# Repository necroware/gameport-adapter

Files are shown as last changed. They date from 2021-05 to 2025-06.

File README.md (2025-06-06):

# Necroware's GamePort Adapter

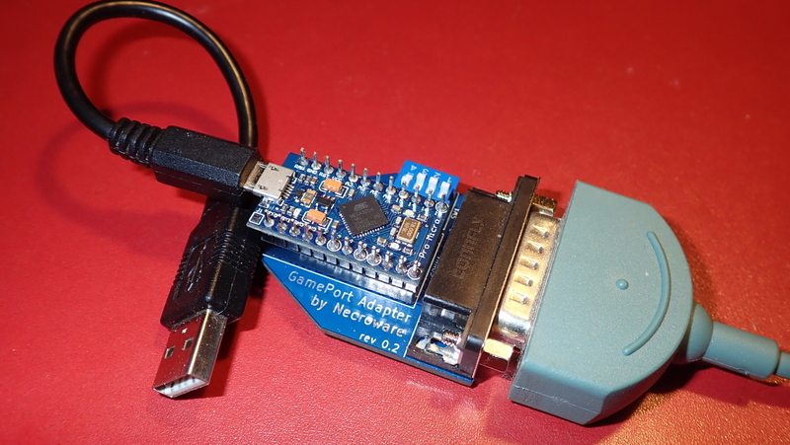
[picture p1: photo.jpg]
GamePort Adapter


Many people from the retro community still have their beloved joysticks and
gamepads from the early days. These devices often live their lives somewhere in
the dark corners of our basements and we don't dare to throw them away, because
of nostalgic reasons. They remind us so much of our childhoods, where we played
our Wing Commanders, X-Wings, Descents and many other games. These old joysticks
were all made to be connected to the game port, usually on a sound card. But
by the end of 90's and beginning of 2000's game ports vanished from our
computers and were replaced by USB and our old joysticks disappeared into the
past. Today not everybody has a full retro PC and many people are using their
modern computer with  DOSBox to play the old games, sometimes with a modern
USB joystick. But wouldn't it be great to play the old games with the same
joystick which we used back then? And this is where this adapter comes into
play. It can be used to connect gameport joysticks to a USB port.

GamePort Adapter Videos:
* [Part 1: Introduction](https://youtu.be/tSJLgCD8jeM)
* [Part 2: Updates](https://youtu.be/947DewHwbsE)

## How does it work?

The adapter is built around Arduino Pro Micro, which uses the same ATmega32U4
microcontroller as Leonardo. This microcontroller has built-in USB HID
capabilities and can be used to build HID input devices, like joysticks. The
adapter itself is super simple, the main brainwork was invested into the
software. Very much simplified, it reads the joystick states and sends the data,
via USB, to the computer, which thinks that it is communicating with a USB 
joystick.

## What is special about this one?

There are already plenty of gameport to USB adapters for basic analog joysticks
and, as far as I know, there were some efforts to communicate with Sidewinder
joysticks by Microsoft as well. But there is no universal adapter, which would
work with different types of joysticks. This adapter implements multiple drivers
for various analog and digital joysticks, with an option to add more, in the 
future.

Features overview:
* Support for generic analog joysticks with 2/4 buttons and 2/4 axes
* Four switches to select joystick type
* Autodetection for various digital protocol joysticks
* Auto-Calibration
* Very low input lag

## What is the difference between analog and digital joystick?

Many people call button-only joysticks or gamepads digital. This is kind of
right, because a button is either pressed or not. You can't have an analog
values in between. However by digital, in this case, we mean something different.
A gameport contains 15 pins, 8 of which are used for joystick communication. 4
pins are for buttons and carry digital values in sense of on/off and 4 pins are
for analog axes, which deliver voltage somewhere between 0V and 5V. Joysticks
which were made in the early days used this pinout. They could have a
maximum of 4 buttons and 4 axes and were DOS compatible. Later, in the time of
Windows 95/98 many joysticks were made to be plugged into a gameport as well,
but they were not limited to 4 buttons and 4 axes. They had a lot more exciting
features, like hat switches and throttle controls. But how did this work? Well
the manufacturers implemented their drivers to communicate with the joystick via
gameport using a proprietary communication protocol. For example, by using one
pin of the gameport as clock and another one as data, the possibilities were
almost limitless. Such joysticks are called digital as well, because they used
digital protocols to communicate with the PC. And suddenly, many features were
possible, but the price of these features was the lost compatibility to DOS. You
couldn't just plug such a joystick into the gameport and expect it to work in
old DOS games. The plug was the same, but the signaling was completely different.

## Which joysticks does this adapter support?

Currently, the following drivers are implemented. To select the right driver, you
have to use four switches, as shown in the table. The switches may be changed or
extended in the future, so please pay attention to the updates.

Joystick Model               | Buttons | Axes  |  Hat | SW1-4 | Protocol   | Comments
-----------------------------|---------|-------|------|-------|------------|------------------------------------
Generic Analog               | 2       | 2     | 0    | 0000  | Analogue   |
Generic Analog               | 4       | 2     | 0    | 1000  | Analogue   |
Generic Analog               | 4       | 3     | 0    | 0100  | Analogue   | 3rd Axis is throttle
Generic Analog               | 4       | 4     | 0    | 1100  | Analogue   |
CH FlightStick               | 4       | 4     | 1    | 0010  | Analogue   |
CH F16 Combat Stick          | 10      | 3     | 1    | 0110  | Analogue   |
ThrustMaster                 | 4       | 3     | 1    | 1010  | Analogue   | FCS MARK I/II & PFCS
Sidewinder GamePad           | 10      | 2     | 0    | 1110  | Sidewinder |
Sidewinder 3D Pro            | 8       | 4     | 1    | 1110  | Sidewinder |
Sidewinder 3D Pro Plus       | 9       | 4     | 1    | 1110  | Sidewinder | First version of Precision Pro
Sidewinder Precision Pro     | 9       | 4     | 1    | 1110  | Sidewinder |
Sidewinder FFB Pro           | 9       | 4     | 1    | 1110  | Sidewinder | FFB not yet implemented
Sidewinder FFB Wheel         | 8       | 3     | 0    | 1110  | Sidewinder | FFB not yet implemented
Gravis GamePad Pro           | 10      | 2     | 0    | 0001  | GrIP       |
Logitech WingMan Extreme     | 6       | 3     | 1    | 1001  | ADI        |
Logitech CyberMan 2          | 8       | 6     | 0    | 1001  | ADI        |
Logitech WingMan Interceptor | 9       | 3     | 3    | 1001  | ADI        | 2 hats are mapped as 4 axes
Logitech ThunderPad Digital  | 8       | 2     | 0    | 1001  | ADI        | Directional buttons mapped as 2 axes
Logitech WingMan Gamepad     | 11      | 2     | 0    | 1001  | ADI        | Directional buttons mapped as 2 axes
Logitech WingMan Light       | 2       | 2     | 0    | 0000  | Analogue   |

*Remarks:*

- Please pay attention to how the same switches are used for different families
of digital devices. This is possible due to fully digital communication. Using
this method, the adapter implements autodetection as soon as it knows, that it
is connected to a digital joystick.
- Currently, only the drivers for the listed Sidewinder devices are implemented,
since I have no other models at hand. The Precision Pro works natively on USB
as well, but was still implemented, because we can.
- Gravis used their GrIP protocol, which is currently implemented only for the
Gravis GamePad Pro, but without daisy chaining possibility so far.
- The implementation of the ADI protocol used by Logitech should work with all
the devices which support that protocol. However only the listed Logitech devices 
were tested so far.

## Which joysticks were tested?

Many joysticks in the wild are using the same digital protocol or are backwards
compatible to the analog joysticks as they were used back in the days in DOS.
Following list contains all the devices which were reported by others as working
so far:

* CH Mach I+ (analog, 2-axes, 2-buttons)
* Gravis Analog Pro (analog)
* Gravis GamePad Pro
* Gravis PC GamePad (analog)
* InterAct UltraRacer PC (analog)
* Logitech CyberMan 2
* Logitech WingMan Extreme Digital
* Logitech WingMan Interceptor
* Logitech WingMan Light
* Logitech ThunderPad Digital
* Logitech WingMan Gamepad
* Medion Joypad MD9823 (analog, 4-axes, 4-buttons)
* QuickShot QS-123E "Warrior 5" (analog)
* Quickshot QS-146 "Intruder 5" (analog)
* Quickshot QS-151 "Aviator" (analog)
* QuickShot QS-201 "Super Warrior" (analog)
* QuickShot QS-203 "Avenger" (analog)
* Sidewinder 3D Pro
* Sidewinder 3D Pro Plus
* Sidewinder ForceFeedBack Pro
* Sidewinder ForceFeedBack Wheel
* Sidewinder GamePad
* Sidewinder Precision Pro 

Sidewinder 3D Pro can be switched between analog and digital mode and in analog
mode it can emulate the ThrustMaster and CH FlightStick. That's why you see them in
the table above. Unfortunately I don't possess those joysticks in reality, so it may
be that the implementation is not quite correct.

## What is auto calibration?

Old analog joysticks have resistors inside, which are specified to be 100 kOhm.
Unfortunately, these resistors are either worn out, bad quality or were wrong from
the beginning. Therefore most of the generic analog joysticks had adjustment
screws to correct the center point of the joystick. Also many games had
calibration options in their settings to readjust the joystick. With USB and new
digital solutions the calibration was not required anymore and was completely
implemented in the joysticks and/or drivers. Many modern games have no option
to re-calibrate the joystick anymore. If we try to play such newer games with
an old analog joystick through this adapter, the joystick center point would be
totally offset. That's why the adapter implements auto calibration internally and
presents already corrected values to the operation system. 

__ATTENTION__: a hard requirement for using the analog joysticks is that during 
plugging into the USB port all axes must be in their middle state, because all
the subsequent calibration happens based on the initial state.

## Technical insights into implementation

The code is well documented, so if you are interested in the details, feel free
to take a look into the driver implementation. All the analog joysticks were
actually a straight forward task, but the Sidewinder digital protocol was kind 
of tough. There are already some implementations of Sidewinder protocol made for
Arduino. However, they are mostly only for the Sidewinder GamePad and not really 
universally made. In the end I was heavily inspired by the Linux Sidewinder 
driver implementation. The code you can see in this project is a complete rewrite, 
I just took the Linux driver implementation as a reference to understand how it 
works. Also the Sidewinder patent US#5628686A helped a lot, especially with 
switching between digital and analog mode for Sidewinder 3D Pro.

In opposition to the already mentioned Sidewinder for Arduino implementations,
this one doesn't rely on interrupts. This implementation is from a similar idea 
to what the Linux driver does. It polls the port and makes a lot of things
simpler due to synchronous process. The biggest problem was that the Sidwinder
devices send the data incredibly fast, with a clock pulse of only 5us. It was
not possible to use Arduino's digitalRead(...) function for that. It was too
slow with about 2.7us per call on an Arduino Pro Micro of 16MHz.  It simply
made it impossible to poll 5us pulses, with such a slow function, not even
considering doing something with the data in between. So out of that need, my 
own implementation came about, which is up to 50% faster and needs only about 
1.6us per call, on the same hardware. The custom I/O functions made it possible
to read the data with the speed which a Sidewinder joystick requires. The best 
part is that the code is written in pure C++. It is very simple to read and to 
use. There are no macros, no assembler or any dirty hacks, just a lot of
optimization.

## Bill of materials (BOM)

The hardware is super simple. To build an adapter you'll need the PCB from this
project and following parts:

Part    |  Qty  | [LCSC](https://lcsc.com/) #  | [Digikey](https://www.digikey.com/) #                | [Mouser Electronics](https://www.mouser.com/) # | Comment
--------|-------|---------|--------------------------|----------------------|------------------------------------------
CONN1   |   1   | C77835  | 609-5371-ND              | 523-L77SDA15SA4CH4F  | DB15 female connector
R1..R4  |   4   | C172965 | 13-MFR-25FTE52-100KCT-ND | 603-MFR-25FTE52-100K | 100 kOhm resistors
SW1     |   1   | C15781  | 2449-KG04ET-ND           | 642-DS04T            | DIP-4 switch
U1      |   1   | C72120  | ED3051-5-ND              | 649-DILB24P-223TLF   | DIP24 Socket (optional)
U1      |   1   |   N/A   | 1568-1060-ND             | 474-DEV-12640        | Arduino Pro Micro (ATmega32U4 16MHz, 5V), including two 12 pin header connectors, MicroUSB version (see "Known issues")

## Known issues

* *Some axes on an analog joystick are offset*

   Auto calibration requires all the axes to be in the center position during 
   initialization. Please see the paragraph about auto calibration.

* *Joystick doesn't work*

   Make sure that you are using one of supported joysticks or a joystick which can
   work in legacy analog mode

* *MicroUSB port on the Arduino is not stable enough*

   Use the USB-C version of the Arduino instead.  
   Or always keep the MicroUSB cable attached to the Arduino MicroUSB version to avoid further wear and apply plug/unplug operations only on the remote side of the cable.

## How to help the project?

The best way is to implement more drivers. Since I have only the joysticks
mentioned above, I can't contribute more than what is currently included.

## Special thanks

I would like to give some special thanks to *Creopard* from the German 
dosreloaded.de community for providing me the mentioned joysticks. Without that
donation this project wouldn't be possible. Especially dealing with Sidewinder
3D Pro was a very exciting task.

## Links
* [Linux Sidewinder Driver](https://github.com/torvalds/linux/blob/master/drivers/input/joystick/sidewinder.c)
* [Sidewinder patent](https://patents.google.com/patent/US5628686A/en)
* [Creopard Retro Site](https://www.creopard.de/)

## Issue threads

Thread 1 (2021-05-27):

digital mode switching necessary?

git-moritz, 2021-05-27:
as far as I understand, we don't need to initialize the Sidewinder 3D Pro into "digital transfer mode" at all... every "trigger" causes the joystick to transmit a 64-bit-package, regardless of mode. the only advantage of digital mode is that IF we use both trigger lines (X1 and Y2), the joystick will transfer triplets instead of bits, which allows for transmission error correction.

since we are only using single-line-transfer, is there any reason why we even _try_ to switch into digital mode?

necroware, 2021-05-27:
Hi Moritz and thank you for the donation first of all :)

We need to switch into digital mode even when using only single line transfer. In analog mode joystick will not react on any trigger signals and will instead emulate CH FlighStick or Thrustmaster analogue joystick, dependent on the current joystick setting.  You can just use the 3D Pro in CH FlightStick mode as well, it is already a feature rich configuration, but in that case you would only have 4 buttons and the hat switch would only work in 4 ways. To use the full features set of the 3D Pro, you need to set it into digital mode.

git-moritz, 2021-05-27:
that's actually not true :)
I used parts of your code to make a sketch that only uses readPacket (via readState) without ever calling enableDigitalMode, and it works just as well.
This behavior is in fact documented in US Patent # 5628686A:

**"The first interrupt request is interpreted by the digital joystick 102 as the Send Data command. In response to the Send Data command, the digital joystick 102 transmits the 64-bit data packet with digital position data and button data, as described above."**

(the sequence that switches the stick into digital mode consist of four interrupt requests - the first of these is already a "Send Data" command!)

**"A single mode data bit is also included in the 64-bit data packet. The mode data bit indicates whether the digital joystick 102 is operating in the Digital Transmission Mode 300 (see FIG. 4) or in the Analog Emulation Mode 302 as well as the type of conventional joystick 10 being emulated if in the Analog Emulation Mode."**

The 64-bit-packet can be transmitted in ANY mode, and even _tells_ you the mode it's currently in. (We could, in fact, even use the mode switch as an additional input "button"...)

necroware, 2021-05-27:
Which joystick did you use to test it? At least on my 3D Pro it doesn't work. The initial state is analog mode and you can try to trigger it as much as you want, you'll get no response. I analyzed it with logic analyzer and without the "magic sequence" it doesn't do anything. I'll get two more Sidewinder joysticks in the next days, one is again a 3D Pro the other is Precision Pro , and see how they react. I have here a Sidewinder GamePad as well and that one is initially in digital mode already and works the way you describe, but not the 3D Pro. A side note, the SW GamePad has 15 bits packages and not 64. Also the GP can be set into information state as well and deliver 72 bit  packages with firmware version info and such things. I don't use it currently.

git-moritz, 2021-05-27:
I am using my Sidewinder 3D Pro. The position of the analog emulation switch does not appear to matter.
As far as I understand, the "full" digital mode was supposed to be used for possible future versions of sidewinder devices, which could be combined: one device acts as a "hub" and relays all data to the PC - additional devices are connected to the first device. For that, a higher transfer rate would have been necessary, which is why they used all four button lines.

git-moritz, 2021-05-27:
...aaaaand of course I made a stupid mistake and did not realize that the "readState" function calls "enableDigitalMode" via "reset".

so I guess you are right, the sequence is needed after all. funny, because the patent says it is not. hmm.

necroware, 2021-05-27:
Yes, the adapter makes auto reset, in case the read fails for some reasons. Very similar approach is made in Linux kernel module as well. I noticed read errors from time to time on my test setup, so I also implemented an auto-reset in case of on-going problems.

In regards of the patent, it is just a hint and not necessarily a document, where it is defined how the whole thing exactly has to work. So we can't completely rely on every statement in there. In the end all the Sidewinders are working similar, but in details differently though.

git-moritz, 2021-05-27:
I suppose I'll close this issue, then :)

Closed 2021-05-27.

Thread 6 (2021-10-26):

Support for logitech wingman extreme digital 3d

fgma, 2021-10-26:
I've read in a forum post you are working on this. Any news on this?

necroware, 2021-11-01:
I implemented the initial support for the Logitech devices. It is currently only tested with the Logitech Wingman Extreme Digital joystick, but hopefully it will also work with other Logitech devices as well. Unfortunately I have no other devices....

Currently the implementation is ready to be tested on the #7 branch

fgma, 2021-11-01:
Perfect! I will try to test this during the next few days.

fgma, 2021-11-02:
It works for me. My joystick just has some issues with the Y-Axis range an generally a lot of dead motion in the center. Don't know if it is just my particular hardware or if it is a general problem.

necroware, 2021-11-02:
That's good news, since the protocol is used universally for all the digital Logitech devices and I was not sure, if my implementation will work with something else, than the Wingman Extreme Digital. Regarding your Y-Axis issues, does it only happen with that one? Are the other axes (X, Throttle) alright? As I got my (used) Wingman Extreme Digital the X-Axis didn't work at all, it jumped wildly left and right. I had to open the Joystick and spray some dioxide on the potentiometers. May be it's the same issue with your device. What about buttons and hats, do they work properly on your Model?

fgma, 2021-11-02:
I got a wingman extreme digital 3d. All buttons and the hat work. Tested using gamepad-tester.com. Only axis1 (y-axis) doesn't really center for me.

Closed 2021-11-05.

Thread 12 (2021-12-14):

Support for the SideWinder Force Feedback Pro

afmenez, 2021-12-14:
The [SideWinder Force Feedback Pro](https://en.wikipedia.org/wiki/Microsoft_SideWinder#Force_Feedback_Pro) was like a Precision Pro with motors for force feedback effects.

afmenez, 2021-12-22:
I have this device and I would be willing to take a shot implementing this, but currently I have no access to the adapter.

No0ne, 2022-02-02:
Hi! I have a SideWinder Force Feedback Wheel and I just tested sniffing the MIDI output from my Win98 PC while the original driver is running.
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
Maybe this works by setting up a USB MIDI interface within the adapter and just forwarding those SysEx and other messages? But I think the hardware needs to be modified so that the TX of the onboard UART is connected to the MIDI out pin.

necroware, 2022-02-02:
That's awesome! Thank you very much. I will take a closer look at it on the weekend. So far I don't use the RX/TX pins on purpose, because I like to keep the serial  port free for debugging. That makes the life easier during the development. I usually do this in all of my Arduino projects and use the RX/TX only if I need a really fast serial connection.... I'll have to think about it.

But your data is already very exciting and gives a lot of stuff to think about ;)

No0ne, 2022-02-02:
Cool! I've another issue, how to debug this?
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
I'm just slowly turning the wheel and pressing the pedals but there seems some bits to be shifted around?

caradas, 2022-02-02:
I tried to implement daisychaining on the SW Gamepad last weekend and had something looking almost exactly the same.
The problem was that the 3rd bit of the 3-bit wide bus was read to late.
To confirm it i changed the order of lines 176-178 on Sidewinder.h to move the problem arround by reading b1 or b2 last.

No0ne, 2022-02-03:
Thanks, but I tried every of the six permutations, didn't make any difference 🤔

No0ne, 2022-02-03:
Ah, just discovered the serial debug feature:
```
Trying to enable digital mode
Guessing model by packet size of 0
Trying to enable digital mode
Guessing model by packet size of 0
Trying to enable digital mode
Guessing model by packet size of 0
Trying to enable digital mode
Guessing model by packet size of 11
Detected model 4
Detected device: MS ForceFeedBack Wheel
Packet decoding failed 1 time(s)
Packet decoding failed 2 time(s)
Packet decoding failed 3 time(s)
Packet decoding failed 4 time(s)
Packet decoding failed 5 time(s)
Packet decoding failed 6 time(s)
Sidewinder init...
Guessing model by packet size of 11
Detected model 4
Packet decoding failed 7 time(s)
Sidewinder init...
Guessing model by packet size of 11
Detected model 4
Packet decoding failed 8 time(s)
Sidewinder init...
Guessing model by packet size of 11
Detected model 4
Packet decoding failed 1 time(s)
Packet decoding failed 2 time(s)
Packet decoding failed 3 time(s)
Packet decoding failed 1 time(s)
Packet decoding failed 2 time(s)
Packet decoding failed 1 time(s)
Packet decoding failed 2 time(s)
Packet decoding failed 3 time(s)
Packet decoding failed 4 time(s)
Packet decoding failed 1 time(s)
Packet decoding failed 1 time(s)
Packet decoding failed 2 time(s)
Packet decoding failed 1 time(s)
Packet decoding failed 2 time(s)
Packet decoding failed 3 time(s)
Packet decoding failed 4 time(s)
Packet decoding failed 5 time(s)
Packet decoding failed 6 time(s)
Sidewinder init...
Guessing model by packet size of 11
Detected model 4
Packet decoding failed 1 time(s)
Packet decoding failed 1 time(s)
Packet decoding failed 2 time(s)
Packet decoding failed 1 time(s)
Packet decoding failed 2 time(s)
Packet decoding failed 3 time(s)
```

necroware, 2022-02-03:
I opened a new issue about the timing issues to keep this one about FFB Pro

opensourcerebel, 2022-03-13:
@No0ne I am trying to implement FFB for the sidewinder wheel - do you have that sniff in a text format? Or any other resources for that manner?

No0ne, 2022-03-13:
Shure, I will try to connect my mt32-pi and just save the midi output coming in via gpio to a text file and upload it here.

opensourcerebel, 2022-03-13:
@No0ne no need, in this wiki there is enough data: https://code.google.com/archive/p/adapt-ffb-joy/wikis/SidewinderFFBWheel.wiki

Hedda, 2022-07-03:
Any news on Sidewinder FFB Pro support?

necroware, 2022-07-03:
> Any news on Sidewinder FFB Pro support?

Unfortunately no, I have no FFB device and nobody contributed to the implementation so far. However, I know, that couple of people are trying to implement this.

Hedda, 2022-08-04:
@necroware Do you live in Europe and would be willinng to look at implementing support for SideWinder Force Feedback Pro?

My OCD made me collect a few over the years and I might be willing to contribute one if add FFB GamePort Adapter compatibility.

PS: I remember reading someone released a SideWinder FFB firmware for Teensy but not sure if they ever made it open source(?):

https://www.descentbb.net/viewtopic.php?t=19061&start=280

https://code.google.com/archive/p/adapt-ffb-joy/downloads

https://www.reddit.com/r/hotas/comments/qd3kow/ms_sidewinder_ffb_pro_teensy_and_now_it_works_on/

https://github.com/tloimu/adapt-ffb-joy

https://github.com/tloimu/adapt-ffb-joy/wiki

PPS: I by the way also read that Immersion Corp's Force Feedback patents have expired since a few years back now:

https://www.reddit.com/r/hotas/comments/bmnr8f/as_of_today_immersion_corps_force_feedback/

https://patents.google.com/patent/US6275213

https://patents.google.com/patent/US6424333

CyberLuke-GBG, 2022-08-06:
Hi, I'm another software dev and I have this Sidewinder Forcefeedback Pro (USB version). I have a small experience with Arduino and MIDI.

Currently I bought a great joystick InterAct FX Racing Wheel (SV-281) and it does have force feedback and gameport connector. It works in the same manner as this Microsoft one. It requires sound card with midi (mpu-401) interface. Gameport features both midi in, midi out and serial connection. So it sends MIDI directly to soundcard via gameport and the software driver in the OS will use it for force feedback. It is quite simple. You just need to parse MIDI. The hard part is how to implement USB HID with force feedback for DirectX input?

I definitely need to write something for this InterAct. It's for RC cars, Trackmania, etc. And the issue is it works only in Win98 due to 16-bit VxD driver. There is no WDM driver for Windows 2000/XP.

I just need to buy some Teensy or Arduino first.

I think the hardest part here will be modifying Arduino USB HID library to output force feedback data and make it work with DirectX input layer.

cyberluke, 2022-08-06:
Hi, I'm another software dev and I have this Sidewinder Forcefeedback Pro (USB version). I have a small experience with Arduino and MIDI.

Currently I bought a great joystick InterAct FX Racing Wheel (SV-281) and it does have force feedback and gameport connector. It works in the same manner as this Microsoft one. It requires sound card with midi (mpu-401) interface. Gameport features both midi in, midi out and serial connection. So it sends MIDI directly to soundcard via gameport and the software driver in the OS will use it for force feedback. It is quite simple. You just need to parse MIDI. The hard part is how to implement USB HID with force feedback for DirectX input?

I definitely need to write something for this InterAct. It's for RC cars, Trackmania, etc. And the issue is it works only in Win98 due to 16-bit VxD driver. There is no WDM driver for Windows 2000/XP.

I just need to buy some Teensy or Arduino first.

I think the hardest part here will be modifying Arduino USB HID library to output force feedback data and make it work with DirectX input layer.

necroware, 2022-08-06:
Hi guys, I also got InterAct FX Racing Wheel (SV-281) some time ago and already was trying to reverse engineer the protocol. I made additional pluggable part, which can be inserted between the joystick and the gameport to grab the communication with a logic analyzer. So it is in the works, but I currently don't know yet how much time it will take to develop everything completely. The SV-281 currently doesn't work at all with this adapter, so the whole protocol has to be reverse engineered. Unfortunately I didn't find any protocol documentation so far.

Hedda, 2022-08-07:
> @necroware Do you live in the EU and are willing to look at implementing support for MS SideWinder Force Feedback Pro?
>
> My OCD made me collect a few over the years and I might be willing to donate one if it adds FFB GamePort Adapter compatibility.
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
Hedda, 2023-02-02:
> Cool, [tloimu](https://github.com/tloimu) made a stand-alone Force Feedback Tester -> https://github.com/tloimu/adapt-ffb-joy/tree/master/FeedbackTester

> FYI, Dirks Software also has a small free Force Feedback Diagnostic Program made for quickly testing MS FFB2 on Windows:
>
> https://www.fs-force.com/support.php -> https://www.dirks-software.ca/downloads/ForceTest.exe

Also check out this project meant to bring Force Feedback functionality to Elite Dangerous but could probably be useful for more:

https://github.com/bobhelander/EDForceFeedback

fedit.exe under /EDForceFeedback/FFUtils/ is btw apparently Microsoft Force Editor that was included with DirectX back in the day.

https://documentation.help/Force-Editor/fedit_7xdg.htm

There also looks to be some other related Force Feedback unitilities software there too:

https://github.com/bobhelander/EDForceFeedback/tree/master/EDForceFeedback/FFUtils

Hedda, 2023-02-28:
Any updates on your Microsoft Sidewinder Force Feedback Pro support for Necroware's GamePort Adapter?

Noticed that initial commits for MS FFB Pro without force-feedback support were merged in https://github.com/necroware/gameport-adapter/pull/48 (which replaced PR https://github.com/necroware/gameport-adapter/pull/45).

https://github.com/necroware/gameport-adapter/tree/sw-ffb-pro

necroware, 2023-02-28:
Unfortunately I still have no FFB Pro joystick. I added correct detection, but there is one report without sufficient information, that the initialization doesn't work. Unfortunately, I can't investigate one that.

Hedda, 2023-03-06:
> Unfortunately I still have no FFB Pro joystick. I added correct detection, but there is one report without sufficient information, that the initialization doesn't work. Unfortunately, I can't investigate one that.

@necroware my offer stands if reconsider a donation of either $30/€30 or one of my Mircosoft SideWinder Force Feedback Pro.

A tip is can still find the original Mircosoft SideWinder Force Feedback Pro for less on different eBay and similar sites in Europe.

* https://www.ebayweb.com/ebay-international-sites
  * http://www.ebay.de
  * http://www.ebay.fr
  * http://www.ebay.it
  * http://www.ebay.com.es
  * http://www.ebay.co.uk
  * http://www.ebay.nl
  * http://www.ebay.ch
  * http://www.ebay.at
  * http://www.ebay.be
* http://allegro.pl
* https://www.ricardo.ch
* https://www.tradera.com

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

christian-georg, 2024-10-05:
@necroware If you can walk me through the steps I can look at the output from the serial console.

Hedda, 2025-07-14:
FYI, @NolanNicholson has developed and released the ”Picowinder” project which is a RP2040-based USB adapter for the Microsoft Sidewinder Force Feedback Pro joystick that includes force-feedback communication:

- https://github.com/NolanNicholson/picowinder

In the credits there it sais that the project uses a lot of information from the [adapt-ffb-joy](https://github.com/tloimu/adapt-ffb-joy) project, and from the [reverse-engineering](https://www.descentbb.net/viewtopic.php?t=19061) that went into it. In addition, several forks of adapt-ffb-joy, including those by [juchong](https://github.com/juchong/adapt-ffb-joy) and [jaybee](https://github.com/jaybee-git/adapt-ffb-joy), provided additional insight.

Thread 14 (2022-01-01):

Build instructions for both physical device and firmware

nikitalita, 2022-01-01:
Are there instructions available on how to build this device?

And also how to build the firmware?

necroware, 2022-01-01:
You mean, how to solder it? There is not much to say, four resistors, joystick port and an Arduino. And if you want to know how to build an Arduino projects, I'd suggest to start with something simple, like blinking LEDs. The Arduino IDE has a lot of nice examples for the beginners.

creopard, 2022-01-01:
The firmware has to be opened directly in the Arduino IDE. It will then be able to compile it for you and can transfer the compiled result directly to the connected Arduino board via USB.

nikitalita, 2022-01-01:
Where did you get the custom PCB for the dip-24-to-DB15? Can we buy that somewhere?

amak79, 2022-01-03:
@nikitalita

You can use a PCB manufacturing service like JLCPCB or PCBWay. All you need to do is upload the `gameport-adapter-gerber-v0.2.zip` file from the releases page and you will be given a quote.

msgit0, 2022-01-04:
I was hoping for something like a schematic diagram to understand what pins on the DB15 connect to which pins on the Arduino, and how the resistors fit into the circuit.  I've been trying to create a similar device for AGES using a Teensy 2.0 board (similar to Arduino).  My joystick is the Logitech Wingman Digital Extreme, using what I hear is the Logitech ADI protocol (something else I can find no information on).  I have only been successful at reading the state for the basic 4 buttons.

necroware, 2022-01-04:
This is an open source project. Here you can find all the circuits, the PCB, the software and the ADI protocol implementation among other digital protocols. Everything is open, so I really don't get the point of your question.

msgit0, 2022-01-04:
Thank you for the prompt reply.  I have downloaded the code, and it appears I need to install KICAD in order to view the schematic.  I'll do that now.

rdfry, 2022-02-24:
Nikitalita the board is self explanatory.

nikitalita, 2022-02-25:
I built it myself, I understand it now :)

Closed 2022-02-25.

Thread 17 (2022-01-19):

Create a How It Works document

msgit0, 2022-01-19:
Hello,
I am very interested in knowing how this project works, however interpreting the C++ is my hurdle.  I've spent hours following the code, but continue to not understand much of it, particularly the reading/writing of the Arduino pins. Is there appetite in this community for an operational specification which is programming language agnostic?  I'm willing to give it a shot to write one, however I will require someone to assist with interpretation of the actual code.
For what it is worth, I believe there is considerable interest in interfacing legacy game port controllers with USB, particularly with electronics enthusiasts like myself.  Hours of searching confirms this interest, and this particular project is as close as I've gotten to understanding.
I'm also new to GitHub, and don't know the protocol for direct messaging between participants.
Much appreciated.
Mike

p.s. This is a QUESTION, not an ISSUE.  Being new to GitHub, I can't see the option to mark this as a question.  Sorry.

necroware, 2022-01-19:
Hi Mike,

first of all every joystick in particular works slightly different, that's why there is no one solution, which can be explained. Furthermore, the code IS already the best and most detailed explanation how it works, so there is no way around it. It is a bad idea to write the same stuff again with the same level of details, but in another language (let it be a human language). It is a very bad software development practice to repeat yourself, which leads to a lot of long term confusion and work. Just imagine, that you have to change the implementation for some reason, then you would have a discrepancy between the description in a programming language and the human language.

You would also have a hard time to make this project language agnostic, since it would be nearly impossible to get the required timings using another languages but C/C++ or Assembler. And to be honest, this is out of scope of this project to explain how USB and I/O works with Arduino. You can find a tone of information about that in a more appropriate places on the internet. The same is for C++.

So, long story short, you will not come around the C++ code if you want to understand how this whole thing works in depth. If you just want abstract information, you can read the official documentation or watch my video on youtube.

Cheers!

msgit0, 2022-01-19:
Hi necroware,
Your response is very respectful - thank you.  I have watched your YT video, which is how I found this project.  Please note that I already know how USB and IO work with Arduino.  What I'm struggling with is how your C++ code manages the specific IO pins to 'talk' to the game controller (joystick).  My specific interest is the Logitech support - the ADI protocol.  For example, I understand the concept for an ADI device is:
   1. Initialize the joystick (i.e. put into "digital mode")
   2. Poll the joystick for current states of buttons, axes, and hats
   3. Send the corresponding joystick commands to the USB channel
   4. GOTO 2

I haven't got past the 'Initialize' step in the code.  Here is the trail I've followed:
- init() (in the class Logitech)
- calls: enableDigitalMode(), which iterates through a list{} of ADI specific delays. Before each delay it calls: m_trigger.pulse()
- the pulse() function calls toggle(), delays for 10u, and calls toggle() again.
- what toggle() does is "m_output ^= m_pin.mask;"  I know that "^=" is XOR, but this is where I get lost with my lack of C++ expertise.  I suspect the code it setting one of the digital pins, but I can't follow the trail any further to see which pin.  I have spent considerable time trying to understand your code.  I've also spent time reviewing Vojtech Pavlic's ADI joystick driver code, but the challenge is that his code is talking to a game port with outb(0xff, ...), not directly to a joystick on specific pins.

This is why I'm committed to writing a document which explains the process to control/read an ADI joystick with a microcontroller such as Arduino.  I do understand that this isn't actually in scope for your project, but I believe it will add value to others who find your project and wish to fully understand 'electronically' how this thing works - at least on the joystick side of the equation.

If anybody reading this Issue thread does know exactly how the code works (regarding sending and receiving signals to the ADI joystick), I would be very grateful to ask you questions to help me write this "How the ADI protocol works".

With thanks.

necroware, 2022-01-21:
I see. Well, the XOR has nothing to do with C++, this part is totally language agnostic and is about to read the MCU ports, as Arduino calls them. The difference between my code is that I'm using Arduino suite to program the MCU and Vojtech probably used a pure C. I went with the Arduino suite, because it is easier to understand for newbies, since you don't need to mess around with compilers and makefiles directly and you can get a lot of help on the Arduino forums, if you need.

If you want to understand what happens in that part, I'd suggest to read about direct port manipulation on Arduino first. Just to understand, what XOR/OR/AND are for in that scope. Once you understand how to read and write from the ports, you will understand this code. The basic idea is to improve the performance of digitalRead() and digitalWrite() functions, which are far too slow for this project. Those functions doing a lot of work trying to map the physical pin IDs to the bits in the registers and calculate the bit masks every time. This whole information doesn't need to be done on every call, since neither the IDs nor the bit masks will change during the runtime, that's why those things can be calculated exactly once in the constructor. This increases the performance dramatically. All the rest should be self explaining I guess.

Closed 2022-09-15.

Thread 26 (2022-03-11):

FFB wheel giving 0 -512 or 1024 when turning the wheel, only one wheel button works

opensourcerebel, 2022-03-11:
Well more of an info in case anyone hits the same issue.
When I saw this project I was super excited to resurrect my old FFB Sidewinder Wheel.
So what I did was immediately to pull an arduino 23u4 and some Dupoint cables connected to a breadboard and used only the +5V, GND, DATA, CLOCK pins. Device detection was working but package reading was randomly failing.

The solution was connecting *ALL* of the pins of the MALE DB25 on the sidewinder ffb wheel. I guess some of them are used for reference voltages or the 100K resistors to ground are used for something ... I do not know.

But in case someone experiences such erratic behaviour with sidewinder FFB wheel - make sure all your adapter pins are connected!

(you can close this issue or may be leave it a bit open for google to index it - however you see fit)

p.s.
For the sidewinder precision pro joystick  +5V, GND, DATA,CLOCK only is sufficient :)

creopard, 2022-06-27:
@opensourcerebel Don't know if that's helpful in any way, but I found some ancient information regarding gameport & wheel support:

> The connection is made so that when both pedals are released, the joystick interface sees about **50 kohm** resistance. When gas is pressed (and break is kept up) the resistance increases and gets maximum resitance when gas pedal is fully pressed down. When the break pedals is fully pressed and gas pedal is released, the pedals system gets the minimun resistance.

https://web.archive.org/web/20130217101121/http://www.q1.fcen.uba.ar/materias/iqi/joygus/pc_special.html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

and a very nice electrical wiring schematic:
https://web.archive.org/web/20040402124145/http://www.monmouth.com/~lw4750/electrical.htm

necroware, 2023-10-14:
FFB Wheel was reported as working multiple times already, so I close this ticket for now. Should this issue appear again, we can create a new ticket.

Closed 2023-10-14.

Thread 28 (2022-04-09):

Machined-pin socket in bill of materials

keronian, 2022-04-09:
The socket that was called out in the Bill of Materials is for machined pin (round) headers.  This causes problems if trying to insert an arduino using the standard square pins that it comes with.

Should either switch the BOM to something like 3M5467-ND or 3M5479-ND or at the very least call out the need to get machined-pin breakaway headers like maybe 1988-1163-ND?

necroware, 2022-04-10:
Already resolved with with this pull request:
https://github.com/necroware/gameport-adapter/pull/27

Closed 2022-04-10.

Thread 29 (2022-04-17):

Support for "WingMan INTERCEPTOR"

gassganso, 2022-04-17:
Interceptor is visually similar to EXTREME with more buttons and hats.
I've tried 1001 configuration (Digital protocol (ADI)) but it shows only one axe an 2 buttons (none of then responfing at all any way).
If is there is anything I can do from my side to help, let me know.

necroware, 2022-04-17:
That joystick should work out of the box. Unfortunately I don't have it to debug, but probably there is some kind of timing issue, so the packet is not decoded properly.

creopard, 2022-06-27:
The Wingman Interceptor has 3 hats in total.
@gassganso did you try the latest version from the main-branch [as the DigitalPin.h was optimized](https://github.com/necroware/gameport-adapter/commit/4e5c81255e7af782aab8c76239a49beb2d331b5b).
Can you also try the debug mode and see what messages the Serial Monitor puts out on initilization?

creopard, 2022-07-03:
As the Interceptor has 3 hats in total, it may be necessary to edit "joystick.h". The maximum of hats are defined as 2:
`MAX_HATS{2u}`

necroware, 2022-07-03:
> As the Interceptor has 3 hats in total, it may be necessary to edit "joystick.h". The maximum of hats are defined as 2: `MAX_HATS{2u}`

Done.

necroware, 2022-09-15:
Any news on this one? Or shall I close it for now?

gassganso, 2022-09-17:
I'll take the project back in the future but it's not possible for me to work on it at the moment. (sorry)

ruenes1, 2022-10-15:
>

I'm also trying to make a Logitech Interceptor work with the adapter, but so far I've been out of luck.

I plan to make a dedicated adapter for this joystick and put it inside the base of the joystick, so I have already disassembled it.
The native gameport cable uses 7 pins, which I've wired to the Arduino as follows:

`Cable color // Gameport pin number // Arduino Pro Micro Pin`
`Black ------------- 4 ------------------------  Gnd`
`Red --------------- 1 ------------------------ VCC`
`Green -------------  14------------------------ D7`
`White -------------  10------------------------ D16`
`Yellow ------------ 7------------------------- D8`
`Orange ------------  2 -------------------------D10`
`Grey --------------   3 ------------------------ A0`

Since there are no analog signals for the Logitech ADI protocol, I've not connected the 100k resitor to pin A0 and gnd, should I?

I see that gameport pins 7, 2 and 3 above correspond to those used in the Logitech.h code, but the joystick also seems to use gameport pins 10 and 14, which I'm not sure are supported by the current code.

When setting the adapter to Logitech mode (which I do by hard coding a "return new Logitech" in the gameport-adapter.ino createJoystick sketch instead of the current code), I get an error when trying to access to the Windows joystick control panel ('your device is not properly connected'). If I manually change the joystick type (e.g., to generic types), the Arduino is properly recognized as the corresponding joystick type (axis/buttons) but, obviously, nothing works.

On the other hand, if I enable debug messsages in the code, the only info I get on the serial monitor is:

`Detected device:
`

Do you have any ideas of things I could try? I would be happy to test and debug any change to bring support for this great joystick.

necroware, 2022-10-15:
I didn't test the Interceptor yet, since I simply don't have the device. It should actually work out of the box, there are more pins, than used in the code, because the joystick can be used in different bit modes, as far as I remember. Current software doesn't use that modes and so some signals should remain unused. I guess, there is some issue with packet reading code, may be due to some timing problems. I think some debugging is needed to get an idea, what's wrong.

ruenes1, 2023-02-11:
Just in case it may be of any use, Linux natively supports a variety of Logitech ADI joystick, including the Interceptor. The code for reading data packets with the used parameters and timings can be found here:

https://github.com/exploiteers/Logitech-Revue/blob/master/revue/src/linux/drivers/input/joystick/adi.c

necroware, 2023-02-11:
> Just in case it may be of any use, Linux natively supports a variety of Logitech ADI joystick, including the Interceptor. The code for reading data packets with the used parameters and timings can be found here:
>
> https://github.com/exploiteers/Logitech-Revue/blob/master/revue/src/linux/drivers/input/joystick/adi.c

Yes it was used as a reference to understand how ADI works. Somebody, who has the Interceptor just has to test it.

Fanbotica, 2023-09-09:
I have a glorious Logitech Wingman Interceptor, I just made a homemade copy of Mr. Necroware's gameport-adapter designed to make the pins available for listening with a Logic Analyzer using dupont cables. I connected the Logic Analyzer like this:

**Logic An.        Arduino         Gameport**
CH1                3                     A0
CH2                2                     10
CH3                7                     8
CH4                10                   16
CH5                12                   5
CH6                14                   7
CH7                15                   9
CH8
GND
GND               GND               GND

Only the following pins appear to emit signals: the **Gameport 3 pin** (Declared as trigger in the Logitech.h file), the **Gameport 10** "Data 1" pin (which instead in the Logitech.h file appears to be replaced with Gameport 2 "Data 0" pin ), and finally the **Gameport 14** "Data 2" pin (which instead in the Logitech.h file appears to be replaced with Gameport 7 "Data 1" pin).

I proceed to replace the two pins in the firmware that seem incorrect and carry out a series of tests. I hope to update you soon with the results.

Fanbotica, 2023-09-14:
TEST N°1 - I proceeded to set the trigger on 12MIDI_TXD of the gameport in the "logitech.h" file (Following the suggestion of a certain Nuke who says that the only Gameport Output Pin of the game port is 12MIDI_TXD)

FW-name---LOGIC2------LOG-AN-----GAMEPORT-----ARD ProMicro
TRIGGER----Channel4----CH5---------12MIDI_TXD-----5
DATA0------Channel1----CH2----------2BUTTON_1-----A10
DATA1------Channel2----CH3----------7BUTTON_2-----8

IN THIS TEST YOU FINALLY READ THE TRIGGER SIGNAL ON THE CHANNEL OF WHICH I REPORT THE OUTPUT:

HIGH------------LOW
73.718ms-------35.375us
9.458us---------4.002ms
9.458us---------2.001ms
9.458us---------3.001ms
9.458us---------10.003ms
9.458us---------6.002ms
9.458us---------11.003ms
9.417us---------7.002ms
9.417us---------9.003ms
9.458us---------11.057ms
23.625us--------5.467ms
23.625us--------5.221ms
23.667us--------5.221ms...

As regards Channel1 and Channel2 they remain silent, while:

Channel3(GAMEPORT10BUTTON_3/ARD16) and Channel5(GAMEPORT14BUTTON_4/ARD7) emit signals synchronized with some falling edges of Channel4,

Channel7(GAMEPORT13AXYSY_2/ARD-A6) instead repeats the inverted signal of Channel4, spacing the copy signal by 5.083us compared to the original.

Ideas on this?

necroware, 2023-09-14:
MIDI ports on Gameport are usually used only for MIDI and Force Feed Back. Otherwise this neither MIDI RX nor TX should be interesting. Interceptor uses the same protocol as the Extreme, if it doesn't work, may be there is just some timing issues. The code from Logitech.h should work out of the box and if it doesn't I'd analyze if the initialization and reading works properly.

Fanbotica, 2023-09-14:
> Le porte MIDI su Gameport vengono solitamente utilizzate solo per MIDI e Force Feed Back. Altrimenti né il MIDI RX né il TX dovrebbero essere interessanti. Interceptor utilizza lo stesso protocollo di Extreme, se non funziona, potrebbe esserci solo qualche problema di tempistica. Il codice di Logitech.h dovrebbe funzionare immediatamente e, in caso contrario, analizzerei se l'inizializzazione e la lettura funzionano correttamente.

Tnks necroware, at this point I test the default configuration again (logitech.h) and will update you shortly with the times of the signals recorded by the logic analyzer. Then I will subsequently carry out a series of tests on the timing, and for these I will ask for your help.

Fanbotica, 2023-09-14:
These are the test results performed with the default pin configuration (logitech.h). The graphs with the times of the signals recorded by the logic analyzer can be downloaded from here as a "sal" file produced and readable by the Logic 2 software from Saleae Inc:
https://drive.google.com/file/d/1p5_Q8X7FMXgZoZpQYt9xQH2sSPVPB16X/view?usp=sharing

Fanbotica, 2023-09-15:
At the beginning of the trigger sequence before the train of signals interspersed with low levels with the duration: 4, 2, 3, 10, 6, 11, 7, 9, 11 milliseconds, I noticed two high signals, the first of 750ns followed from a low signal of 28ms, then the second of 102us followed by one of 45ms.

Fanbotica, 2023-09-18:
EUREKAAAAAAAAAAAAAAAAAAA!!!!!!!
Yes!!! Finally!!!! Timing problem solved!!!
After a series of attempts, I managed to find the right duration for the offending timing! This is the duration of the pulse described on line 222 of the "Logitech.h" file which must be modified with "32u", like this:

   Packet readPacket() const {
     static const auto TIMEOUT = 32u;

Thanks to Necroware of course for the magnificent work done but also for the tips provided to resolve the case!

Closed 2023-09-20.

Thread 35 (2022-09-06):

Feature Request: Add Schematics

speendo, 2022-09-06:
Hello and first of all thank you for this project!

I tried to revive my old Sidewinder 3D Pro about a year ago utilizing the information from this project (https://www.descentbb.net/viewtopic.php?f=8&t=15526&p=250537#p250537). At least on a modern Linux, I didn't succeed however. The joystick did sometimes show up on the system but the output was more than strange. With this project, I have high hopes to make it work again.

I understand that ordering a PCB and all the other parts is the most convenient solution. However, as I have many "similar" parts at home already, I would like to try and solder the connections myself. Most likely I will be able to figure out which pins need to be connected by looking at the Gerber files.

However, if it was possible to provide the schematics in a separate file (e.g. as an image generated with Fritzing (https://fritzing.org/), this would make it much easier for people like me...

Anyway: thank you again for your effort!

speendo, 2022-09-10:
So I tried to do it myself and came up with this

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

However, I did this for the first time, so I am not sure if it is correct.
@necroware, can you confirm my drawings? In case they are correct I can also provide the Fritzing file and you can of course use them in the repo, if you like.

necroware, 2022-09-10:
Hi, sorry for the late answer, I'm currently short on time. The project contains all the schematics. Just open it with KiCad to see the schematics and the PCB layout. No need to draw it yourself :)

speendo, 2022-09-15:
Thank you!

I feel a little stupid that I didn't find that on myself.

It seems that installing KiCad (which is quite a heavy tool in terms of ressources) was too much of a hurdle to me...

Why not taking a screenshot of the KiCad schematics and adding it to the readme?

necroware, 2022-09-15:
Hi KiCad is not that much heavy and if you work with electronics design, I highly suggest to use something like that. I don't provide an image separately, because I highly dislike to be repetitive and adding an image would mean duplication of what is already included in the KiCad project. Duplication is a bad practice, it always means additional maintenance effort and a source of errors, if s.o. forgets to updater one of the parts. For example image could start to diverge from the KiCad project and result in a lot of confusion. I ran into such problems in another projects already and so I try to avoid duplication as much as possible.

speendo, 2022-09-15:
I understand your argument. Thank you for pointing me the way!

Closed 2022-09-15.

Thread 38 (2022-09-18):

Support for additional controllers

crashdot, 2022-09-18:
Hi,

I am wondering if there is anyone that who develops drivers for this adapter that is interested in adding support for additional controllers of this era if I'm willing to donate controllers for this purpose.

Thanks!

CyberLuke-GBG, 2022-09-19:
Hello, I spent last month by adding FFB support in vJoy and FreePIE for USB controllers here: https://github.com/cyberluke/FreePIE/tree/Ffb

I would like to look at Necroware some time, but I don't have Necroware device itself and currently I'm helping two other open-source projects.

Currently I need to learn to compile Windows XP driver using DDK and 7.1 driver. I can compile only kernel Win 10 driver now.

It would be great, if there would be someone, who could do it.

What specific controllers you have in mind? I might reorder my priorities a little bit or it might help others as well.

necroware, 2022-09-19:
@CyberLuke-GBG When talking about drivers, the internal driver in the microcontroller firmware is meant and not Windows/Linux whatsoever.
@crashdot which controllers do you have? May be some of them do work already, or just have to be tested.

crashdot, 2022-09-19:
Greetings,

I may be able to donate a Necroware adapter along with the controllers.

I would need to go through my storage to see if any other controllers are worth considering, but the ones that I can think of immediately are:

Mad Catz Panther XL Joystick (Joystick with trackball)
Interact Force Feedback FX Racing Controller (Radio Controlled car remote style racing controller)
Logitech Wingman Warrior (Joystick with spinner)

The Wingman Warrior has both a gameport and serial port connector, but using the gameport limits its function, since only the joystick part of the controller will work. With the gameport connection, it is supposed to emulate a Logitech Wingman Extreme, however I tried that dip switch setting with the Necroware adapter and it identifies as a "SparkFun Pro Micro" and says "Your game controller is not connected correctly".

With a serial port connection, both the joystick and spinner are available. Someone suggested that the Necroware device could be adapted to translate the serial port input, but I don't know if that is possible. I've tried the Wingman Warrior through a USB to Serial adapter going into DOSbox, but cannot get the entire controller to be recognized. The DOS drivers are intended to install the joystick as a serial mouse and joystick "dual device", but the driver says it only detects one of the devices. In any case, gameport support could be evaluated if serial is not possible.

In any case, I would be willing to donate these and a Necroware adapter if needed (assuming I can find one) to anyone who is willing and able to add support for these controllers.

Cheers

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

necroware, 2022-09-19:
A driver for the "Interact Force Feedback FX Racing" is already in the works. The "Logitech Wingman Warrior" seems only to be powered through the game port, but the whole communication seems to happen through the serial port, so my adapter is quite useless with it. The "Mad Catz Panther XL Joystick" I see for the first time and probably protocol reverse engineering would be required here.

cyberluke, 2022-09-19:
Yes, we discussed the Interact in another thread, I have that one. I was thinking there be some Windows driver change required, but I guess you can just use sidewinder ffb pid profile as that is what vJoy does on Win XP.

The one with serial port could be worked out using something like FreePIE, manually routing data using Python script. This way I made the Thrustmaster FCS, mark II and weapons systems mark II working. They have AT DIN connector, which I connected to PS/2 adapter and then to USB adapter. The throttle sends real keys 0 to 9 to control throttle and simulate analog control. I just made Python script than converts these keys to joystic axis.

That solution. I’m sharing here: https://gist.github.com/cyberluke/baaadd29bd01fcd6d6e47de3569c3482

In a similar fashion, you could access Arduino or this joystick serial port inside FreePIE. Adding serial port to real Necroware hardware would be the next step, of course.

I also wrote Teensy USB keyboard to AT DIN, so you can use modern mechanical keyboard with retro design on, lets say 386DX. It would be great if there could be several modules like this in Necroware format and users could just plug n play them using I2C or SPI bus via cable or magnetic pins.

Next thing I’m doing now is connecting two gameport joystics using breadboard, so I can use them on 486 in Descent 1 for 6DOF. The important thing is to use 4 buttons on first joystick, including POV switch and connect only X2,Y2 axis without buttons of second joystick. I will be making Youtube video about that.

I would like to get Necroware and help with Interact code, but don’t see any branch.

necroware, 2022-09-19:
The branch is not yet public, unfortunately I have a very hard deadline on my daily job currently and I don't even have time to release a video on my YT channel.

crashdot, 2022-09-20:
> "Logitech Wingman Warrior" seems only to be powered through the game port, but the whole communication seems to happen through the serial port, so my adapter is quite useless with it.

The documentation indicates the gameport and serial ports are used separately, and they should not be connected at the same time. If used as a gameport controller, it is supposed to emulate a Logitech Wingman Extreme, although I could not get this working with the Necroware adapter settings for this controller. When connected to the gameport, the spinner does not work. Presumably, gameport support could still be added for this joystick in it's emulation mode.

The serial connector is used on its own, which gives full support for the spinner and joystick. I was able to use an RS232 DB9 to USB adapter to run the Wingman Warrior through DOSBox on Windows 10, where it loads the correct DOS driver and I can play Tempest 2000 for DOS using the spinner and joystick buttons.

This controller can't be used on modern Windows via the serial connector without DOSbox as far as I know, since the drivers are only for DOS or Windows95.

Cheers

necroware, 2022-09-20:
@crashdot I see. But if it emulates "Logitech Wingman Extreme", than you have to set the adapter to "Generic Analog" joystick and not to Logitech. The Wingman Extreme is not a digital joystick, but a generic analog one. You should only use Logitech setting on the adapter with digital joysticks, which use the ADI protocol, like the "Logitech Wingman Extreme Digital".

crashdot, 2022-09-21:
Hi,

Thanks for clarifying that. I can confirm that the Logitech Wingman Warrior seems to work in its two gameport modes with the Necroware adapter as follows:

I don't have a manual for this controller, but I *think* that it is not intended to be able to use the throttle and hat at the same time, but rather there is a switch to select which one you want to use.

1010 - Joystick switch in Hat position = works as 2 axis, 4 button joystick with 4 direction hat controls
1100 - Joystick switch in Throttle position = works as 3 axis, 4 button joystick with the 3rd axis being the throttle wheel

Thanks!

CyberLuke-GBG, 2022-09-21:
@necroware Why it is not public? I remember we are discussing it for over a month or even more. When it will be public? You can tag me here, I will work on it later. But maybe I am busy at that time, who knows....a kid is on the way

crashdot, 2022-09-24:
I tried the different switch settings for the Madcatz Panther XL and could not get any response. It apparently uses a different protocol called A3D. The good news is that someone has apparently figured out the protocol and written Linux drivers for this controller, so perhaps there is documentation that would permit this function to be added to the Necroware adapter at some point. I should be able to donate the controller if needed.

https://github.com/datrh/joyutils

necroware, 2022-09-24:
Yes, the implementation of A3D is available in Linux Kernel directly:
https://github.com/torvalds/linux/blob/master/drivers/input/joystick/a3d.c

It doesn't look too complicated, but I don't have that joystick and currently also very short on time to do the implementation. So may be s.o. else would like to try?

crashdot, 2022-09-24:
I've been storing these controllers for as much as 25 years, so I can surely wait until you have more time to work on such things. Please let me know if you get to a point when you would like me to send the controller to you. Thanks

crashdot, 2023-01-18:
Hi there,
I'm checking to see if there has been any movement on the release of support for the "Interact Force Feedback FX Racing" controller, and if anyone is interested in taking on the "Madcatz Panther XL" as I can donate a controller.

Thanks for your consideration

necroware, 2023-01-18:
Nope, unfortunately still didn't have time for it. Sorry.

beachbouy, 2023-04-12:
I have a Gravis eXterminator gamepad with both serial connector and the USB adapter that came with it. I'd love to get it working again. It last worked on XP with its driver and customising software - Gravis Experience. Is there any chance it would work with the current Gravis "driver" you've implemented? Would it be reasonably easy to add to your code myself? I have some coding experience, but not so much with arduino yet.

Thanks for this awesome project.

creopard, 2023-04-12:
The Gravis Xterminator gamepad seems to send 4 bits long packages (the Gravis Gamepad Pro uses 24 bits, see https://github.com/necroware/gameport-adapter/blob/main/firmware/gameport-adapter/GrIP.h).

In the Linux driver (https://github.com/ilbers/linux/blob/master/drivers/input/joystick/grip.c#L124) exists a function "**grip_xt_read_packet()**" that seems to be a little more complex to initialize the Gravis Xterminator.

Ronnuss, 2024-03-29:
> Interact Force Feedback FX Racing

Did you have any success in implementing the Interact FX Racing Wheel?
Would be a godsend ;-)

necroware, 2024-03-29:
I started, but unfortunately I had no time to continue.

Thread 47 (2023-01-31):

How to create an own adapter?

necroware, 2023-01-31:
It is then relatively easy for most hobby/amateur-tinkers to solder the parts by hand as it only has very few simple component, see:

https://www.youtube.com/watch?v=HUmbvfqP784&ab_channel=chadaustinak

## Ordering prototype PCB and assembling yourself

As this is [open-source hardware](https://en.wikipedia.org/wiki/Open-source_hardware) you should know as an option that it is today relatively easy (and inexpensive) to just submit the KiCad PCB layout files directly to some PCB-prototype board manufacturers like Oshpark or PCBWay who will take it then make + ship a few of the PCB boards to you, all without you having to use KiCad yourself or even having to understand the PCB layout:

- https://oshpark.com
   - See example shared project (rev 0.2.1 of the board) -> https://oshpark.com/shared_projects/rzwJjMoP
- https://www.pcbway.com
- https://jlcpcb.com

FYI, Chinese PCB manufacturers will usually make around 20 simple PCB board like this for less than $10 and ship them to you for around $20, so depending on your country's import tax you have those at home for around $30-40 in around a months time.

E.i. just buy the ones from the project BOM (Bill-Of-Matierials) list

https://github.com/necroware/gameport-adapter/blob/main/README.md#bill-of-materials-bom

Note! It is not recommended to buy the Mini-USB variant of Arduino Pro Micro as its header is wider than USB-C and Micro-USB variants), and it is not recommended to buy the Micro-USB variant of Arduino Pro Micro as it is too easy to break the connector.

## Bill of materials (BOM)

The hardware is super simple. To build an adapter you'll need the PCB from this project and following parts:

Part    |  Qty  | [LCSC](https://lcsc.com/) #  | [Digikey](https://www.digikey.com/) #                | [Mouser Electronics](https://www.mouser.com/) # | Comment
--------|-------|---------|--------------------------|----------------------|------------------------------------------
CONN1   |   1   | C77835  | 609-5371-ND              | 523-L77SDA15SA4CH4F  | DB15 female connector
R1..R4  |   4   | C172965 | 13-MFR-25FTE52-100KCT-ND | 603-MFR-25FTE52-100K | 100 kOhm resistors
SW1     |   1   | C15781  | 2449-KG04ET-ND           | 642-DS04T            | DIP-4 switch
U1      |   1   | C72120  | ED3051-5-ND              | 649-DILB24P-223TLF   | DIP24 Socket (optional)
U1      |   1   |   N/A   | 1568-1060-ND             | 474-DEV-12640        | Arduino Pro Micro (ATmega32U4 16MHz, 5V), including two 12 pin header connectors, MicroUSB version (see "Known issues")

Tip! Some other user recommended buying an enclosure case: Hammond Manufacturing 1551RTBU, Digi-Key Part # HM1142-ND.

You can otherwise 3D-print your own case, see example -> https://www.thingiverse.com/thing:5457006

## Firmware

Once you have it and want to flash the firmware yourself (to ensure you have the latest version), you can do that yourself as well.

1. Download source code files from -> https://github.com/necroware/gameport-adapter/tree/main/firmware/gameport-adapter
2. Download the Arduino IDE from -> https://www.arduino.cc/en/software
3. Connect the Adapter with your USB cable.
4. Open "gameport-adapter.ino" included in the source files.
5. In "Tools" -> Port -> select the virtual COM port that says (Arduino Micro).
6. In "Sketch" -> select "Upload" which will compile the firmware and upload it to the Arduino.
7. You are done.

_Originally posted by @Hedda in https://github.com/necroware/gameport-adapter/issues/12#issuecomment-1408782899_

Hedda, 2023-01-31:
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

FYI, today a few of those and other PCB manufacturers (including Oshpark and PCBWay) have communities / community website that allows anyone to create and share projects similar to the linked shared project on Oshpark, and doing so can help make it even easier for less experienced people that might be new to that part of the hobby to order their own PCB board directly.

https://oshpark.com/shared_projects
https://oshpark.com/shared_projects/rzwJjMoP

https://www.pcbway.com/blog/help_center/How_to_Share_Projects_in_PCBWay_Community_d27959dc.html
https://www.pcbway.com/project/
https://www.pcbway.com/project/shareproject/

creopard, 2023-01-31:
Also make sure to get the right Arduino board, as they may differ in width:
https://www.youtube.com/watch?v=0losEHACB6A

Hedda, 2023-01-31:
Oh, btw, most open-source hardware licenses allow anyone to make the board to then resell the board and/or product, see ex:

- https://www.tindie.com/products/retrofletch/pc-usb-c-gameport-adapter-sidewinder-retro-joystic/
- https://www.tindie.com/products/retrofletch/pc-usb-gameport-adapter-sidewinder-retro-joystick/

PS: Open-source hardware licenses does however usually not extend to the copyrighted name of the creator or an unique name that the original creator has given to the project/product, so it would normally not be allowed to market and sell it as "Necroware" product, hence a disclaimer is usually used by others to inform that it is not official or sold by the original creator.

Hedda, 2023-01-31:
@necroware You might want to consider enabling the GitHub Discussions for this repository (GitHub collaborative communication forum feature for repositories)  and move this there as it allows for collaboration threads without clogging up the issues section:

https://docs.github.com/en/discussions

https://github.com/features/discussions

Lowe0, 2023-02-09:
I've built a few of these using boards from OSHpark.  They work pretty well, although the resistors can be a bit of a pain.  I think a lead-forming tool will help a lot with that.

Hedda, 2023-02-13:
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

Tip on other one-stop-shop turnkey PCB and embedded circuit board manufacturers partners which offer open project pages:

- Seeed Studio (Seeed Technology) https://www.seeedstudio.com
- Elecrow https://www.elecrow.com
- PCBgogo https://www.pcbgogo.com
- Makerfabs https://www.makerfabs.com
- OSpcb  https://www.cnospcb.com

YARD2, 2023-02-28:
Created a small adapter myself at PCBWay
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

necroware, 2023-02-28:
Done.

Hedda, 2023-04-17:
Recommend moving this to the suggestion section under discussions -> https://github.com/necroware/gameport-adapter/discussions

Closed 2023-02-28.

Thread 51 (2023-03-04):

Testing Necroware adapter with SwFFBPro

PinkBaron1949, 2023-03-04:
Hi folks, I hope to do this right so here is my current situation:
I now have 5 Necroware boards, 3 with micro connector, 2 with c connector and one SWFFBPro and I did a little bit of testing.
Machines used to test:
ASUS ROG Laptop with Win 10 Home 64 Bit with all updates,
Toshiba Satellite Pro Win 10 Home 32 Bit with all updates,
ASUS Desktop Win 10 Home 64 Bit with all updates.
Used software Arduino v 1.8.19
Firmware v2.1.1 (originally not for SwFFBPro)
Firmware "main" (why is this not v2.1.2 or similar)

1. When flashing all 5 boards with the 2.1.1 firmware and connecting to every machine, the indications are consistent.
2. When connecting, Windows accepts the boards as Arduino pro micro. X,Y Axis do not move and there is no chance to calibrate,
so it seems the Sw is not initilized.
[Sw_Softw_v2_1_1.docx](https://github.com/necroware/gameport-adapter/files/10888935/Sw_Softw_v2_1_1.docx)
3. When connecting it also happens as in the following file documented.
[Sw_Softw_v2_1_1B.docx](https://github.com/necroware/gameport-adapter/files/10888953/Sw_Softw_v2_1_1B.docx)
The X,Y axis is trembling but also reacts at inputs from the joystick, Z axis is trembling but reacts to Z rotation on the joyst., X rotation trembling but reacts to movemant of the X axis, all buttons flicker but correspond to input of the joystick buttons, hats flickers in all direction but also react to coolie hat input on the joystick.
Now I rely on your expertise to investigate the bug. Because I have no knowledge of coding etc. I am only able to test and submit the results.
When using the firmware from the main branch, the results are also consistent with all boards but very different.
[Sw_Softw_main.docx](https://github.com/necroware/gameport-adapter/files/10889021/Sw_Softw_main.docx)
Thats all for today.
Regards.PB

Hedda, 2023-03-06:
@PinkBaron1949  FYI, for reference, there is another existing issue here -> https://github.com/necroware/gameport-adapter/issues/12 however that is specifically requesting/discussing support for the ["Force Feedback" (haptic technology)](https://en.wikipedia.org/wiki/Haptic_technology) with original [Microsoft SideWinder Force Feedback Pro](https://en.wikipedia.org/wiki/Microsoft_SideWinder#Force_Feedback_Pro) joystick via Necroware gameport adapter/firmware, but I believe that you are reporting issues with the MS SideWindows FFB Pro without "Force Feedback", correct?

PinkBaron1949, 2023-03-07:
Because the existing firmware does not work sofar as to be able to calibrate I can not evaluate the FFb.
But yes the stick is a Sidewinder Force Feedback Pro and works fine under LUFA board.
As I said, anybody that can give me guidance where to look for either in Windows or elsewhere I will povide the information.
and test.
Complaining about not enough information is easy. I have no knowledge about coding but wil try to get you the support I can, remember there are five boards that are waiting for testing.
H.P.

necroware, 2023-03-09:
You can use the serial console in the Arduino IDE to find out, what's wrong. The serial output can be enabled by commenting the line `#define NDEBUG` in `Utilities.h`. If you are not familiar with serial monitoring, you can enable serial monitor in Tools menu of the Arduino IDE.

It would be also interesting to know, what exactly Windows is complaining about. The Precision Pro uses exactly the same packet format, only the initialization differs a little bit. You can try to comment the lines 109-113 in Sidewinder.h to make the adapter think, that FFB Pro is a Precision Pro. If this works, we have investigate, what it doesn't like about the FFB Pro path.

PinkBaron1949, 2023-03-11:
Nice try but I have no knowledge about commenting the files, please be so kind and tell or do the commenting, then I will do the testing.

necroware, 2023-03-12:
Duplicate #53

Closed 2023-03-12.

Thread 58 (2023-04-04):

Sidewinder FFB Wheel - detection as gamepad on Steamdeck

EXTgithub99cd2, 2023-04-04:
Hi,

I thought I found a similar description in another issue here about the Sidewinder FFB Wheel being detected as gamepad, but I can not find it anymore. So with the risk of being a duplicate I write my question here.

When I use the Sidewinder FFB Wheel on Windows 10 or Linux desktop (Steamdeck/Arch Linux, desktop mode), it simply works. It is detected as a Sparkfun Pro Micro and/or XBOX 360 Controller. But the wheel and pedals work as 3 axis without problem.

But when I connect it to my Steamdeck in "gaming mode", it is also detected as Sparkfun Pro Micro and/or XBOX 360 controller, but without the 3 axis working. I can get the wheel function as a thumbstick (hard) left/right, I might get the "brake" pedal working as a thumbstick down. However the "gas" pedal does not work at all.

I have found similar detection issues for Logitech wheels being mentioned on reddit with several (deprecated) solutions. One of which eventually referred to the kernel driver for sidewinder (yes, for the Logitech wheels). Then I realised Necroware described using these drivers as a base for the implementation of the gameport adapter. So while I thought this must be a local OS issue, outside of the firmware I seem to end up running circles.

Can someone help Identify where this problem is, is it in the adapter or in the OS? I am confused.

necroware, 2023-04-04:
Hi, the linux implementation is been used as an information source, to understand the protocol, but the implementation in this project has been made completely from scratch. But if some assumptions were made in the linux code, that assumptions could end up in this project as well. The detection of the Sidewinder device happens using the packet length. For the GamePad it's 15 bits and for the FFB Wheel it's either 11 or 33 bits depending on the mode, which the wheel is set into. If for some reason the firmware gets 15 bits package from the FFB Wheel, it could be wrongly detected as a GamePad. I didn't see such issues with another joysticks, but I have no wheel to tell what's going on. I could imagine, that the the initialization sequence fails and the Wheel sends another package, which lands out of sync with the firmware, but I can't validate that.

Logitech and Sidewider code is unrelated here, since it is set by switches which path has to be taken. If set to Sidewinder, Logitech code will not be used at all, and the other way around neither. I'll take a look at the linux code for the wheel once again, may be I can recognize something related.

Does the problem disappear if you re-connect the adapter into USB couple of times?

EXTgithub99cd2, 2023-04-04:
Hi,

thanks for the quick response. The behaviour does not change on reconnecting. Always the same result.
The reference I made to Logitech was only because apparently the sidewinder driver in the kernel is used for Logitech wheels as well, as I understand it anyway. This makes it sound driver related and not directly manufacturer/hardware/wheel related?

And yes, I don't know if this is copied to your project somehow.

If you want me to do some analyses on my side, I am willing to assist if you can guide me on the setup/use of the right tools.
I am however somewhat slower in response :)

necroware, 2023-04-04:
I'm quite sure, that Sidwinder code is not used for Logitech, they are completely different. Sidewinder is patented by Microsoft and Logitech uses own ADI protocol, however linux could have autodetection by probing the gameport and trying to detect it as Sidewinder first. May be in such a case a Logitech device could be detected as Sidewinder ending up non functional. However, as I said, this can't happen here, since the firmware doesn't probe it uses what is set by switches.

I'm looking at the code and don't know currently how that can happen to be honest. There coud be two possibilities, timing issues, the Wheel send the data too fast and the adapter swallows some bits, or the wheel sends an ID package, which is accidentally 15 bit long on a Wheel. It's very hard to tell without debugging. As a workaround, you can modify the function guessModel() in Sidewinder.cpp to always return Model::SW_FORCE_FEEDBACK_WHEEL. This is of course not a solution for the wide audience. Strange is, that it works on other OSes, but not on the Steamdeck, which is basically an ArchLinux, which I'm using all the time since 15 years. The whole development of this adapter is been made there.... very strange. It should actually make no difference, which OS is on the other side of the adapter, it has no influence on how the adapter communicates with the input device.

EXTgithub99cd2, 2023-04-04:
Some reference about a difference in "console" mode and "PC" mode for the Logitech, which resembles my experience for the Sidewinder Wheel in either "Gaming mode" and "Desktop mode"

It mentions "usb_modeswitch".

[Reddit](https://www.reddit.com/r/SteamDeck/comments/vs9foh/how_to_get_your_logitech_racing_wheel_to_work/)
 _Basically, the Logitech wheels have a "console" and a "PC" mode, and when you plug it in to your Steam Deck, the wheel stays in "console" mode, so it doesn't input to a PC like it should._

EXTgithub99cd2, 2023-04-04:
That sidewinder part I seem to misread, I can not find it anymore. But above the issue sounds similar. Just because of the driver implementation I don't know where to look for a solution.

necroware, 2023-04-04:
Well, as I said, actually the OS on USB side of the adapter knows nothing about the communication of the adapter to the joystick. The same on the other side, joystick knows nothing about which OS it is runing on or in which mode the OS is. So, the only thing, which sounds plausible is that Steamdeck just "cuts" down any input device which it doesn't know officialy to something very simple, like a gamepad. I have no Steamdeck to validate, but if you have another joystick, you could try. You also could try ty to set the switches to CH Flightstick for example and see, what Steamdeck will say. You can do it even without connecting any joystick to the gameport at all. It will act as a dummy.

EXTgithub99cd2, 2023-04-04:
I am a keyboard + mouse person, not much else to test with.

I do have a Nintendo Switch and thus have connected joy-cons and Nintendo pro controllers to the steamdeck, however they have been specifically supported to work on the Steamdeck. They don't always connect easy, but they always get recognized correctly when they do connect. I can not think of any other gadget.

I did play with the switches on the Pro Micro in desktop mode, it results in error messages on the Steamdeck (using dmesg -Tw).
I will check what happens in gaming mode, not sure if I can run a console to check while doing that.

necroware, 2023-04-04:
You should be able to setup any analog joysticks on the switches incl. CH Flightstick and Thrustmaster. The adapter sends a generic USB descriptor to the operation system, which should be able to handle it properly. The amount of axes, buttons etc. is in that description packet. If the Sidewinder detects it as GamePad it sends a USB description with 2 axes and 10 buttons. If you see something else in Steamdeck, then the problem is there. If you see 2+10, then it's probably in the firmware and the Wheel detection code.

EXTgithub99cd2, 2023-04-04:
Just connected CH Flightstick DIPswitch 0010 on desktop mode.
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
EXTgithub99cd2, 2023-04-04:
Spend some time reading. Its a lot.

Lots of gamepad desciptions in Steam documentation. Where XBOX360 is apparently some kind of standard.
Xinput seems to come down to Input source mode to "Legacy" , where you can choose and define Joystick Move.

> Joystick Move
> This input will operate as a simple Joystick. This is intended for traditional joystick applications.
> Legacy Note: Joystick will only work with XInput compatible gamepad games
source: https://partner.steamgames.com/doc/features/steam_controller/input_source_modes

The Sparkfun Pro Micro does get detected/described as XBOX360 many times, this being some kind of (gamepad) default. Question remains how to switch to Legacy input source mode there.
Going back to my original question, I think here is the answer: it seems this "gaming mode" is actually only the SteamClient in fullscreen, where driver support gets boxed-in on the SteamClient as opposed to Desktop Mode where the OS takes control of the driver support. Support then depending on the applications to support Xinput.

Would be nice if I can figure this out.

EXTgithub99cd2, 2023-04-04:
Some of the errors when changes made:

lots of:
usbhid 1-1.3:1.2: can't add hid device: -22

once or twice:
usb 1-1.3: can't set config #1, error -32

searchengine suggests it is a timing related issue when disconnecting and reconnecting USB-dongle?

> After a lot of testing and tracing we found out, that when we pull out the usb-dongle ot of the usb-socket just that far that the power-pins are still connected and only the connection-pins are disconnected and then plug it back, the device will be detected just fine. Also when using a external usb-hub it will come up normally.
So it seems the problem comes from a timing issue between the ...  driver and the dongle. Probably the dongle delivers the usb-config too slow so that the kernel has no config to select the further loading of cdc_acm.

EverytimeI had to completely reboot the system after this happened. I can not get the adapter properly connected anymore at such point.

mjack3k, 2023-04-05:
Could it be power issue? After all, this is mobile device. Not sure how the 5V for usb port gets generated - maybe it is enough to drop a little when connecting?

If you have powered usb hub, try connecting it via hub. This should tell if it's powering problem.

Maybe adding a slight delay in code right in the beginning, before anything gets initialized would help?

EXTgithub99cd2, 2023-04-05:
Ow. I was saving my power related questions for a seperated issue ...

necroware, 2023-10-14:
Hi guys, does this issue still exist with the latest state if the firmware and SteamOS? Just trying to clean up some tickets.

necroware, 2023-12-28:
Closing due to absence of news on this one. This bug could have been fixed already with other fixes. If it happens again with the recent firmware, please reopen.

Closed 2023-12-28.

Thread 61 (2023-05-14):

Support for Gravis Xterminator Digital gamepad

timixretroplays, 2023-05-14:
**Background**

The Gravis Xterminator Digital gamepad was a gameport-only controller released in ~1997. It features a pass-through gameport connector and supports using multiple daisy-chained controllers. It only supports a variant of the Gravis GrIP protocol and does not feature a 4-button "1P" mode like the GamePad Pro does.

The Xterminator is readily available on Ebay, but currently cannot be used with any modern system due to its dependence on the GrIP protocol - it would be great to see the Necroware adapter support this controller. Currently, with the Xterminator plugged into my home-built Necroware adapter in GrIP mode, no new device appears in the list of Game Controllers in Windows, which I assume means it fails the validation used to confirm that a GamePad Pro is connected.

**Implementation**

The Xterminator Digital gamepad has an analog thumbstick, a digital D-pad, nine digital face buttons, a POV hat, a throttle slider, two analog triggers and two digital rear buttons.

The "S" button on the front is a "Hot Set Switch Button", originally used for "your favourite cheat moves" - I believe this is "BTN_MODE" in the Linux driver so it should be readable like any other button. Likely the original Gravis software would have reserved this button to switch to a different mapping or to run a macro on its own - this behaviour can be recreated using additional software (JoyToKey, reWASD etc) and would be out of scope for the context of Necroware adapter support.

Support for the Xterminator GamePad exists within the Linux GrIP driver, and it should be possible to implement Necroware support using this and the existing GamePad Pro support for reference: https://github.com/ilbers/linux/blob/master/drivers/input/joystick/grip.c

Note that the Linux driver supports a separate "GrIP mode" for four different devices - the GamePad Pro, the Blackhawk Digital (joystick) Xterminator Digital (this gamepad), and the Xterminator Dual Control (another joystick). If this approach is acceptable, I will raise additional issues to request support for the Blackhawk and DC joysticks; while the Dual Control originally shipped with a USB adapter, its pinout and design are undocumented, and I can see multiple DCs for sale on eBay right now without that adapter, so it would be great to see them supported by the Necroware adapter as gameport devices.

It should be possible to detect which type of GrIP device is attached based on the data packets received from the device, so the DIP switch config of 0001 should be sufficient to switch the adapter to support all possible Gravis GrIP devices.

**Testing**

I personally own an Xterminator Digital GamePad and will enthusiastically test any any attempt to implement support for it.

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

Rikki-Tikki-Tavi-12, 2024-04-09:
Is this still a current issue?

TinaFritz75, 2024-09-11:
Hello, I've the same Gravis Xterminator Gamepad and would like to use it as well.
Apparently, it does not function with the Necroware Gameport Adapter - I thought, it was already implemented in the meantime when I bought it, but sadly, it's a no.

The Xterminator Dual Control 'Joystick' and the Necroware Gameport Adapter, on the other hand, also don't work together - but, I've an original Gravis Gameport Adapter just for that and it runs fine (it's really only for the Joystick, the Gamepad does not function with it).
So, it should be easy to implement, if the programmer get one of them to work around, I guess?

Anyway, thanks for reading. I hope, someone with knowledge about it, could get that into the firmware.

Rikki-Tikki-Tavi-12, 2024-09-11:
@TinaFritz75 I had a look at the code, and I don't think it would be very hard to implement support for it. The basic protocol already works, it's just a matter of reading the Xterminator packages correctly. Do you want to send me the hardware?

timixretroplays, 2024-09-11:
Hi all. Since writing this ticket over a year ago, I've had several developments in my own research:

- There's a couple of different 'versions' of the Gravis GrIP protocol - the GamePad Pro uses a relatively simple one, the Blackhawk and Xterminator gear uses another, and the GrIP multisystem (2 gameport sockets, 4 9-pin GrIP-pad sockets) uses another
- All of these were reverse-engineered 20+ years ago and open-source implementations written, mostly for Linux - I have bookmarks for this code
- There are also actually two different versions of the Xterminator gamepad - one uses the same GrIP protocol as the Blackhawk and Xterminator Dual Control joystick, the other does something different I haven't found any information about yet
- I have personally collected basically one of everything Gravis ever made, and am keen to use this collection to help implement and test support for these devices.

While I've since been able to code and build my own adapter for the GamePad Pro in GrIP mode, I don't quite yet have the programming skills to fully understand the code to talk to these other controllers. I have literally everything else on a shelf here, though, so if someone's keen to check out the resources I've found and take a whack at it, I can support it from the hardware side.

I won't have time until probably the weekend sometime to sit down and list/write out everything, so ask me anything about this pad in the meantime and I'll try and answer it.

Rikki-Tikki-Tavi-12, 2024-09-11:
@timixretroplays
When you have the time, could you elaborate on why you think there are two different versions of the Xterminator gamepad? What did you find about the possible third version of the protocol, not mentioned in the Linux source file.

To be clear, I don't have an oscilloscope good enough to reverse engineer protocols. My only scope is single channel, non-recording. I wouldn't want to go deeper than adapting what is already in the Linux file.

timixretroplays, 2024-09-22:
Okay so, I don't remember anymore exactly how I discovered there are two different Xterminator gamepads, but I've now collected one of each. One comes with a dumb USB to gameport adapter in addition to the Y-adapting gameport plug and will work when plugged into USB (I assume the adapter just links buttons 1 and 2 to the two USB data lines, and VCC and GND as appropriate, but I haven't tested this), the other just has the Y-plug for gameport and nothing will happen if you try plugging it in using the USB adapter. Photos in this post are of the USB-enabled Xterminator gamepad.

It's easy to tell between them. The non-USB one is model #44011, has "Xterminator (and then in tiny text) Digital Game Controller" in green text on the box, just says "GRAVIS Xterminator" on the gamepad itself. The USB-compatible is model #44111, says "Xterminator Digital Gamepad" in white on the box (and says "USB and gameport compatible"), and also says "GRAVIS Xterminator DIGITAL" on the pad itself. (Both gamepads are digital, but one is... more digital than the other.)

Here's probably the biggest, best thread I've found about reverse-engineering the USB one: https://www.avrfreaks.net/s/topic/a5C3l000000UW4wEAG/t137104

Someone named Hyratel pops up later in the thread to share this implementation: https://gist.github.com/Hyratel/4e689925743fb789b5cf3cca3812511a he mentions the timing is super tight on a 32U4-based Arduino, clearly it can be made to work but for my own project I plan to start with a Raspberry Pi Pico 2 as it's just as accessible but a lot faster.

I'm in contact with Hyratel on Mastodon, we chatted a bit about the Blackhawk Digital which basically uses the same "Xterminator" packet as the XT and XDC and I have a (paused) project to re-implement that for myself on a 32U4.

I can't find my source for the tidbit about the two Xterminator pads having different GrIP protocols, it's possible I invented that in my head and both will work fine from the same gameport-pin-bashing code. I haven't gotten as far as testing either XT pad with any code yet.

The Linux GrIP driver is here: https://github.com/ilbers/linux/blob/master/drivers/input/joystick/grip.c it reads "GPP" (GamePad Pro) and "XT" (Xterminator) packets, but I currently have no way to test if it works with both XT pads.

Regarding the third mysterious GrIP spec, here's the most extensive code I've found that talks to the GrIP Multiport: https://android.googlesource.com/kernel/msm/+/android-wear-5.1.1_r0.2/drivers/input/joystick/grip_mp.c I cannot explain how it ended up in Android Wear 5.1, but it's not like this code's changed in 20+ years. This was written by someone else (Brian Bonnlander, not Vojtěch Pavlík) and is better commented, and is clear enough to me to see that the Multiport is a two-way device - data gets sent to it as well as received from it.

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

Rikki-Tikki-Tavi-12, 2024-09-27:
It seems to me like implementing support for the USB-capable version would be lower priority, since it the USB adapter is still readily available. It would be interesting to know what the USB adapter actually does. There could be an IC molded into the plastic, or it could just be connecting some wires up. In the latter case, I would guess that one of the gamepads in line registers as a USB hub (the one at the usb adapter, probably).

creopard, 2025-06-06:
> It would be interesting to know what the USB adapter actually does

@Rikki-Tikki-Tavi-12 The USB adapter has no built-in logic. It's probably the same procedure as with the Sidewinder joysticks from Microsoft. Microsoft e.g. released a [non-USB compatible "Sidewinder Precision Pro" and sometime later a "Sidewinder Precision Pro" with an USB-adapter included](https://en.wikipedia.org/wiki/Microsoft_SideWinder#First_generation) (stating "now USB compatible" on the packaging). Yet the first released version of that joystick [does not work with the included adapter from the second version](https://en.wikipedia.org/wiki/Microsoft_SideWinder#Precision_Pro).
The "magic" is included in the joystick itself, the adapter is just taking care of the wiring.

This circumstance often results in people buying these 'wiring adapters' from eBay and wondering why their joystick doesn't work when connected via USB.

That's why the Necroware gameport adapter was initially conceived. Connect a supported joystick to the adapter and the Arduino will [initialise the joystick in analog/digital mode](https://github.com/necroware/gameport-adapter?tab=readme-ov-file#what-is-special-about-this-one ) and translate the commands.

Rikki-Tikki-Tavi-12, 2025-06-06:
@creopard Did you read my message? With is about the adapter for the Gravis gamepad and how they handle daisy chaining. It could be one of the gamepads assumes the role of a usb hub, or there could be an IC for that in the adapter. This is not about Sidewinder.

Maybe they used the same solution, maybe not. Unless I get to poke around in one with probes, I won't know.

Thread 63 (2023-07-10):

Issues with Logitech Wingman Extreme Digital

bonzaihb, 2023-07-10:
Hi there,

I've just built the adapter to use my old Wingman Extreme Digital with it - unfortunately, it does not want to work properly:
when enabling debug logging and jumpers set to "closed, open, open, closed" (did not have a DIP switch at hand, so I used jumpers instead) I am getting:

Detected device: WMD

so I assume, it is recognized correctly. But it's not doing anything: on W10 it is not recognized at all, and on Linux Mint it's showing as 2 axis, 2 buttons only. Buttons 1+2 are working, everything else no response. The axis behaves really strange as well, jumping all over the place.

Any hint how to check whether its the adapter or the joystick itself? The joystick was left in a corner for sth like 20 years... ;)
My old Gravis 2 Button stick (the black one with 3 buttons and rubber stick) is working with no problems btw...

Cheers,
Christian

necroware, 2023-07-10:
Hi, which firmawre did you use? From main branch, or from particular release? I have one Wingman Extreme Digital at hand, I can check it with the latest version from main once again.

bonzaihb, 2023-07-10:
Thanks necroware, I am using the current main branch.

necroware, 2023-07-21:
Hi, sorry for the late answer. I tested the device and it works fine, but what I noticed going through multiple arduino boards is that the switch is not always detected properly, because I try to read it too fast after the setup. I added some delay there and it should now be more stable. Please try out the latest version from the main branch.

bonzaihb, 2023-07-21:
Hi!
No worries! Just tried it, now it's recognized correctly (most of the time, sometimes takes 2-3 re-connects), buttons working, throttle working, hat working, but the X/Y axis are still messed up. After some waiting time, they seem to normalize in jstest-gtk, but as soon as I just grab the stick, they again start jumping all over the place.
I assume the potis might be dodgy, after all these (25+) years...

Anyways, thanks for your time! :)

necroware, 2023-07-21:
Hm, strange, that it still needs 2-3 re-connects. With all adapters and joysticks which I have it works every time. Before that initialization delay, on some arduinos it also needed some re-connects, but no more. I will keep my eye on it, may be I'll run into it again. Regarding Wingman, yes, the one which I have had also jittery throttle and I had to disassemble the joystick to clean the potis. It worked fine ever since.

necroware, 2023-07-21:
I will close this issue for now. Should it happen again, we can open another one. Btw. this was model independent and the detection could go wrong with any other joystick.

bonzaihb, 2023-07-21:
Quick update: disassembled it and flodded the potis with contact spray, works good now! :)

Closed 2023-07-21.

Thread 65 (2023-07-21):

Microsoft Sidewinder Force Feedback Pro: Everything is Jittery and clicking Buttons

sniperwolfpk5, 2023-07-21:
Dear @necroware,

First of all, I appreciate your hard work. Thank you very much for such a brilliant adapter.

> Please note that I have a [**Sidewinder Force Feedback Pro**](https://en.wikipedia.org/wiki/Microsoft_SideWinder#Force_Feedback_Pro) joystick, not a **Sidewinder Precision Pro** joystick.

> I experimented with the **Arduino Micro Pro** and **Arduino Leonardo** board selections in the Arduino IDE, hoping the issue might be specific to the board type.

I followed the instructions and utilized the available materials to create an adapter using a prototype board. Windows successfully detects and recognizes the joystick, which appears to function correctly as the motors center the joystick upon plugging in the adapter. However, inspecting the Windows joystick manager, I noticed that all the axis movements are jittery and erratic, despite the axes and buttons working. Additionally, some buttons are registering automatic clicks without any input from me.

**Frame 1**
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
**Frame 2**
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

In the Arduino IDE, a message is repeated on the serial monitor. `Packet decoding failed 1 time`

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

I suspected the issue might be related to the wiring or connection on the prototype board. To troubleshoot, I decided to redo the connections a second time, starting from scratch. Unfortunately, even after this attempt, the problem persisted, and I couldn't resolve it.

**My thoughts**
- I think the Sidewinder FF Pro may have a different packet, and the decoding function may not work correctly.
- I grounded all the ground points, as shown in the picture below.
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

I appreciate your help. Please let me know if you need any more information.

necroware, 2023-07-21:
Hi this looks like timing issue. Try to play with trigger and cooldown duration. I have one FFB here which works fine, but there can be slight differences between revisions.

sniperwolfpk5, 2023-07-21:
I will check and I will update you

sniperwolfpk5, 2023-07-21:
Hi @necroware, I tried to change some of the values in the `cooldown`, `delayMicroseconds(1000)` functions, and the value in `wait_duration` in the `readPacket` function without any luck.

For your information, I am not familiar with coding microcontrollers. I am a software engineer (C#, Asp.net, etc.). It is a bit too much for me unless I understand some basics.

From your videos, I understand you created your function to read digital and analog signals from the game port. Since speed is crucial for this task, you need to adjust delays.

Could you provide more details on the range I should try? You mentioned triggers and what to change in the trigger."

necroware, 2023-07-21:
wait_duration is not, what you should change. What you are interested in is cooldown (1-5 ms) and trigger (5-25 µs). It's hard to analyze without a logic analyzer, but may be you can spot some difference when trying other values. I just tried my FFB Pro and it works flawlessly with the code from the main brunch. What you can try is to disconnect the power supply from the joystick to see, if stuttering disappears or at least changes somehow.

sniperwolfpk5, 2023-07-21:
Thank you for your quick response. I will give it a try and get back to you 🙏

sniperwolfpk5, 2023-07-22:
Hi @necroware, it seems that the release version is outdated. After forking your project, I tested the code from the source, and it's working perfectly, except for some minor issues. The axes appear to be a bit jittery. I'm unsure if the z-axis and Rotation-axis use potentiometers, but I know that the central axis is equipped with an optic sensor.

I tried different values for the `cooldown` function, ranging from 0 to 6, and I also tried `pulse` values from 18 to 26. However, values below 18 are not working. Do you have any thoughts on the jittery axis issue?

I have recorded a short video for you.
https://youtu.be/N9WF86b-05I

I appreciate your help.

YARD2, 2023-07-22:
Jitter is a common problem with the FFB.
Also in the FFB project some years ago
https://github.com/tloimu/adapt-ffb-joy
some users had this issue.
The only thing what helped was to average the axis which results in a
slow delay.
The problem was the old optical sensor which drifts.

sniperwolfpk5, 2023-07-23:
Well, due to the jittery axis, the joystick is not usable.
@necroware, you were using a joystick tool in your videos. Where can I find that tool?

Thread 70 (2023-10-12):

Sidewinder 3D Pro does not work in windows but in linux

schuellerf, 2023-10-12:
The discussion started in #69, for me the Sidewinder 3D Pro works in linux but not in windows.
The FFB Wheel I have works in both systems with the same adapter and firmware.

Please hint me how to get proper debug information as I'm more a linux/embedded guy.

The device manager says

```
Device USB\VID_2341&PID_8037&MI_02\8&3153e260&0&0002 had a problem starting.

Driver Name: input.inf
Class Guid: {745a17a0-74d3-11d0-b6fe-00a0c90f57da}
Service: HidUsb
Lower Filters:
Upper Filters:
Problem: 0x0
Problem Status: 0xC00000E5
```

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

schuellerf, 2023-10-12:
More info: My Sidewinder 3D Pro has a serial number starting with 0407XXX and I tested this and the FFB Wheel on two different Windows machines. Both detect the Wheel but not the 3D Pro

creopard, 2023-10-12:
To sum things up:

- Sidewinder 3D does work on Linux, not on Windows _(-> **the Sidewinder 3D does not seem to be broken**)_
- Sidewinder FFB Wheel (same DIP switches) does work on Linux and also works on Windows _(->**the adapter does not seem to be broken**)_
- You already tested on two different Windows machines, but the issue remains.

necroware, 2023-10-12:
Additional conclusion: The joystick works in Linux, but it fails on Windows, that means, that the Sidewinder driver code is working and the USB HID code is probably making problems.

Which firmware did you use? Did you try the latest state from master branch or from an older release?

schuellerf, 2023-10-12:
> Additional conclusion: The joystick works in Linux, but it fails on Windows, that means, that the Sidewinder driver code is working and the USB HID code is probably making problems.
>
> Which firmware did you use? Did you try the latest state from master branch or from an older release?

Totally agree that it has to do something with USB HID...
I work with "main" branch 😊😉

necroware, 2023-10-12:
Does the adapter work if you switch it, let's say into CH Flight Stick mode? Sidwinder 3D Pro can work in that mode too, but the buttons on the base will not work and the hat would have only 4 ways. If that works you can then look into the init routine of the Sidewinder. For the 3D Pro it has to enable the digital mode and read a packet from the joystick before it can generate the HID descriptor. May be this time is too long for windows and it times out the USB connection before it is able to come back with the registration.

schuellerf, 2023-10-13:
I've now got a logic analyzer, I hope that data helps.
It seems that in linux the magic sequence is run once and then the communication starts (at least to the joystick)
whereas when connecting to windows the sequence seems to be repeated 6 times...
I think the pins are connected correctly but the clock and data2 does not seem to do anything, but that might not affect searching this problem.

Linux (where it works)
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

Windows (where the Sidewinder 3d pro is not detected properly)
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

Here are the files from PulseView/sigrok if this is of any interest:
[Gameport_Sidewinder_linux.sr.zip](https://github.com/necroware/gameport-adapter/files/12894182/Gameport_Sidewinder_linux.sr.zip)

[Gameport_Sidewinder_windows.sr.zip](https://github.com/necroware/gameport-adapter/files/12894196/Gameport_Sidewinder_windows.sr.zip)

necroware, 2023-10-13:
Hm, that is strange. The driver should work as shown for Linux. It should try to read the data packet and if it fails, trigger the magic sequence to try to set the joystick into a digital mode. Then again reading the data packet which would then tell which Sidewinder joystick it is. In your windows case it looks like it fails to read, then it makes the magic sequence and then fails to read, and again, and again. The joystick seems not to answer for some reason. You can try to play with the functions trigger(), cooldown() and enableDigitalMode(). Try to set the magic duration to other values, s.t. between 115 and 305.

schuellerf, 2023-10-13:
Hmm - I played around with the timings without any success. Then I checked the difference of the FFB Wheel (which works on my windows) and the 3D Pro which is the "Hat" so I just disabled the Hat in the description of the 3d Pro class and now the joystick works in windows (obviously without the hat)
... I'll continue to experiment what the problem might be with Hat and windows...

necroware, 2023-10-14:
Ok, that is an important find. That means, that with the joystick driver everything is ok and we don't need to search in Sidewinder.h. It's just HID USB descriptor which makes problems. The error must be in HidJoystick.h somewhere around Hat registration. Once again it would be nice if you could try the device using CH Flight Stick mode on the adapter and see if that one works.

Meanwhile I'll try to find a windows 10/11 PC somewhere to be able to reproduce it as well. Probably there is some inconsistency in the USB HID descriptor, which is ignored by linux, but is treated more strictly by windows. May be just some padding issues.

schuellerf, 2023-10-14:
Do you have a link to a proper USB/HID specification so I can check myself?

schuellerf, 2023-10-14:
Tested the other modes now:

Position 1 & FlightStick mode: 0010
what works: x,y,rotation,slider,4 buttons,4 direction hat
no buttons at the same time

Position 2 & ThurstMaster mode: 1010
what works: x,y,rotation,4 buttons,4 direction hat
buttons at the same time

as expected!

schuellerf, 2023-10-14:
Some more tests:
    static const Description desc{"MS Sidewinder 3D Pro", 4, 8, 1};   does not work
    static const Description desc{"MS Sidewinder 3D Pro", 4, 8, 0};   works (without hat)
    static const Description desc{"MS Sidewinder 3D Pro", 4, 4, 1};   works (with only 4 buttons)

necroware, 2023-10-14:
Ok that looks more and more like bit padding problem. I do single padding in the end of the sequence and not after each block, may be Windows doesn't like it. What is strange, the latest state has been tested with windows and Sidewinder 3D Pro, but may be various Windows versions and USB drivers can vary in their strictness.

necroware, 2023-10-14:
I changed the way how padding is applied, may be this helps. Unfortunately I didn't find a Windows 10 PC for testing today, so I can't tell if this makes any difference. Please try to run the firmware from the following branch on your Windows PC.
https://github.com/necroware/gameport-adapter/tree/win10-usb-hid-fix

On Linux this code works, but also the previous version was working fine, so I'm not quite sure.

schuellerf, 2023-10-14:
I randomly changed the padding and now it works 🥳
I only tested windows 7 and windows 11 (don't have win10 nearby)

schuellerf, 2023-10-14:
FlightStick mode now does not work but only with the padding 4.
maybe the padding 8 is only necessary for those 8 "hat directions"
i.e. we could change the "hasHat" to "hatDirections" and use 4 or 8 respectively

schuellerf, 2023-10-14:
Sure my last fix is based on your win10-usb-hid-fix branch

schuellerf, 2023-10-14:
I'll try to find some proper documentation of the protocol as I don't like the trial and error approach I just did 😔

Closed 2023-12-28.

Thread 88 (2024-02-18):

question about use and calibration with Sidewinder 3D Pro

tastez, 2024-02-18:
hi all - this possibly is an issue of a broken Sidewinder 3D Pro (and if likely, will appreciate any pointers on threads youve seen for fixing it)

I've got a SW3D Pro that I assume I calibrate with Joy.cpl in windows 11.
Calibration and testing is completely out of whack with the adapter jumpers setup as in the directions.

I am not sure what the autocalibration is on the adapter or at what point it happens but I assume we need to calibrate it in Windows anyway.

https://github.com/necroware/gameport-adapter/assets/78642112/876004cf-49bf-433e-ae86-5cb006625147

The joystick is also listed simply as SparkFun Pro Micro but I assume thats normal.

thanks for any answers!

necroware, 2024-02-18:
For the digital joysticks auto calibration is not happening in the adapter. It shows what it gets from the joystick. I'd suggest to open the joystick and clean it.

tastez, 2024-02-19:
thanks - guess this thing is finally biting the dust. Looks like the resistors, caps or optical sensor/leds are just too old now and adjusting variable resistors or cleaning isnt getting joy.cpl to calibrate it

necroware, 2024-02-19:
If you have a retro PC at hand, you can also try to test it there. Also you can set the adapter into Thrustmaster Analog mode and see if something changes. Also please be sure, that you take the latest state from the main branch. There have been made some adjustments in timing and device registration.

tastez, 2024-02-19:
uploaded the new code but i think i bricked the pro micro. 🤡

necroware, 2024-02-19:
Disconnect the adapter from everything, turn all switches off, reconnect the adapter to USB and try to flash the firmware once again. If nothing works, you can easily unbrick one arduino using another one. They don't even need to be the same.

tastez, 2024-02-19:
all good,
for other bozos:
i did the GND / RST short twice and got it into bootloader mode then uploaded the sketch to Arduino Micro and i think it works the same as Sparkfun Pro Micro, since sketch seems to run fine.

closing the issue since Im quite sure the Sidewinder is rotten. Will get another one eventually!

Closed 2024-02-19.

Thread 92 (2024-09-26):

Arduino Pro Micro TX RED Diode always on

ihora, 2024-09-26:
Dear sir,

Thank you for your amazing work. I just assembled your gameport-adapter on breadboard and it works excellent!
The only thing I am worried about a bit is that the TX right diode on the bottom part of the Arduino Pro Micro board is shining red anytime the joystick is activated.
Normally I would assume that this is totally correct as the board just started transmitting data, but at the beginning of testing the adapter, I did not have this diode shining red so I hope I did not short circuited my board and this RED diode lightning does not mean that the adapter is transmitting data rather it detected fault.
If TX diode shining red is not a normal state, could you please possible explain me what the issue could be?

Best regards,
Ivo

fandjelo, 2025-02-13:
The diode is connected to serial transmission and the adapter logs info to the serial port. So the led can blink, the adapter code doesn't control it.

Closed 2025-02-13.

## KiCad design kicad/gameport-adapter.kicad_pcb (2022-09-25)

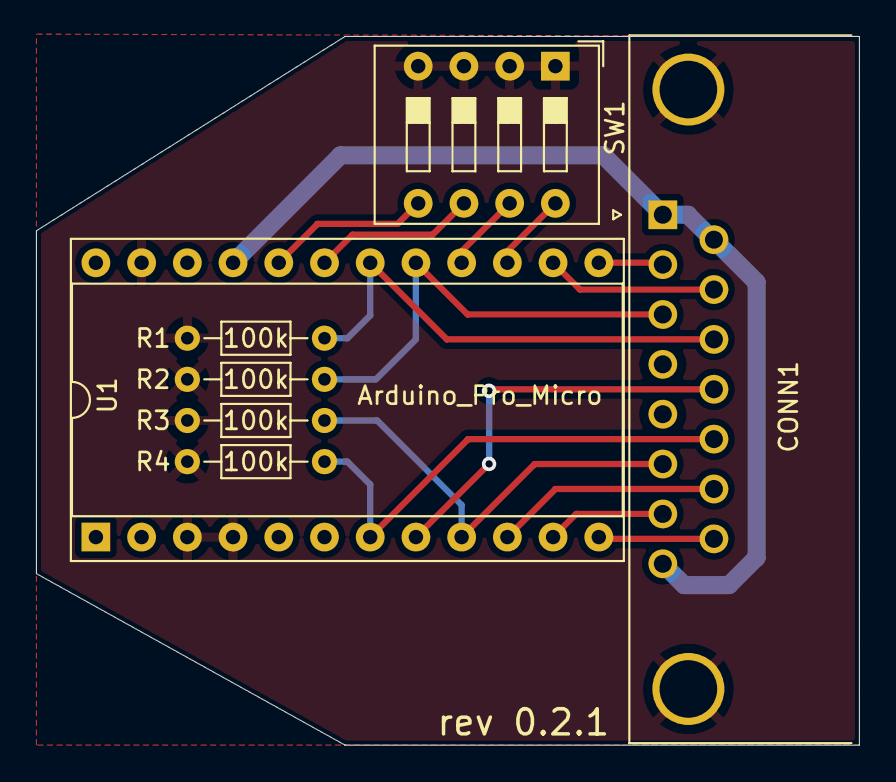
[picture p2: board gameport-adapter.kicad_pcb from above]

Board: 2 copper layers, 45.7 x 39.4 mm, 7 parts (0 on the bottom side), 16 nets.

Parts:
CONN1: GamePort; DSUB-15_Female_Horizontal_P2.77x2.84mm_EdgePinOffset7.70mm_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
R1, R2, R3, R4: 100k; R_Axial_DIN0204_L3.6mm_D1.6mm_P7.62mm_Horizontal
SW1: SW_DIP_x04; SW_DIP_SPSTx04_Slide_9.78x12.34mm_W7.62mm_P2.54mm
U1: Arduino_Pro_Micro; DIP-24_W15.24mm_Socket

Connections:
AxisX_1: CONN1.3, R2.2, U1.17
AxisX_2: CONN1.11, R1.1, U1.18
AxisY_1: CONN1.6, R3.1, U1.9
AxisY_2: CONN1.13, R4.2, U1.7
Button_1: CONN1.2, U1.13
Button_2: CONN1.7, U1.11
Button_3: CONN1.10, U1.14
Button_4: CONN1.14, U1.10
GND: CONN1.0, CONN1.4, CONN1.5, R1.2, R2.1, R3.2, R4.1, SW1.1, SW1.2, SW1.3, SW1.4, U1.3, U1.4, U1.23
MIDI_RXD: CONN1.15, U1.12
MIDI_TXD: CONN1.12, U1.8
SW1: SW1.8, U1.15
SW2: SW1.7, U1.16
SW3: SW1.6, U1.19
SW4: SW1.5, U1.20
VCC: CONN1.1, CONN1.8, CONN1.9, U1.21

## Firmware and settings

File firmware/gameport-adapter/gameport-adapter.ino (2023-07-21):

// This file is part of Necroware's GamePort adapter firmware.
// Copyright (C) 2021 Necroware
//
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
#include "DigitalPin.h"
#include "HidJoystick.h"

#include "CHFlightstickPro.h"
#include "CHF16CombatStick.h"
#include "GenericJoystick.h"
#include "GrIP.h"
#include "Logitech.h"
#include "Sidewinder.h"
#include "ThrustMaster.h"

static Joystick *createJoystick() {

  const auto sw1 = DigitalInput<14, true>{};
  const auto sw2 = DigitalInput<15, true>{};
  const auto sw3 = DigitalInput<20, true>{};
  const auto sw4 = DigitalInput<21, true>{};

  // Give some time to setup the input
  delay(1);

  const auto sw = !sw4 << 3 | !sw3 << 2 | !sw2 << 1 | !sw1;

  switch (sw) {
    case 0b0001:
      return new GenericJoystick<2,4>;
    case 0b0010:
      return new GenericJoystick<3,4>;
    case 0b0011:
      return new GenericJoystick<4,4>;
    case 0b0100:
      return new CHFlightstickPro;
    case 0b0101:
      return new ThrustMaster;
    case 0b0110:
      return new CHF16CombatStick;
    case 0b0111:
      return new Sidewinder;
    case 0b1000:
      return new GrIP;
    case 0b1001:
      return new Logitech;
    default:
      return new GenericJoystick<2,2>;
  }
}

void setup() {
    // DEBUG information: Debugging is turned off by default
    // Comment the "NDEBUG" line in "Utilities.h" to enable logging to the serial monitor
    initLog();
}

void loop() {

  static auto hidJoystick = [] {
      HidJoystick hidJoystick;
      hidJoystick.init(createJoystick());
      return hidJoystick;
  }();

  hidJoystick.update();
}

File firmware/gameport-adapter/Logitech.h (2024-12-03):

// This file is part of Necroware's GamePort adapter firmware.
// Copyright (C) 2021 Necroware
//
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
#pragma once

#include "DigitalPin.h"
#include "GamePort.h"
#include "Joystick.h"
#include "Utilities.h"

class Logitech : public Joystick {
public:
  bool init() override {
    enableDigitalMode();
    if (!readMetaData()) {
      return false;
    }

    // Create joystick description
    m_description.name = m_metaData.deviceName;
    m_description.numAxes = min(Joystick::MAX_AXES,
                                m_metaData.num10bitAxes + 
                                m_metaData.num8bitAxes +
                                m_metaData.numSecondaryHats * 2); // Each hat is mapped to two axes
    m_description.numButtons = m_metaData.numPrimaryButtons + m_metaData.numSecondaryButtons;
    m_description.hasHat = m_metaData.hasHat;

    // If the device is a Logitech ThunderPad Digital, manually redefine the gamepad layout to 2 axes and 8 buttons
    if(m_metaData.deviceID == DEVICE_THUNDERPAD_DIGITAL){
      m_description.numAxes = 2;
      m_description.numButtons = 8;
      m_description.hasHat = 0;
    }
    // If the device is a Logitech WingMan Gamepad, manually redefine the gamepad layout to 2 axes and 11 buttons
    else if(m_metaData.deviceID == DEVICE_WINGMAN_GAMEPAD){
      m_description.numAxes = 2;
      m_description.numButtons = 11;
      m_description.hasHat = 0;
    }

    // Initialize axes centers
    uint8_t axis = 0u;
    for (auto i = 0u; i < m_metaData.num10bitAxes; i++, axis++) {
      m_limits[axis] = { 512 - 256, 512 + 256 };
    }
    for (auto i = 0u; i < m_metaData.num8bitAxes; i++, axis++) {
      m_limits[axis] = { 128 - 64, 128 + 64 };
    }

    return true;
  }

  bool update() override {

    // === Status packet format ===
    //
    // Offset Bits  Description
    // --------------------------------------------------------
    // 0      4     Low nibble of the Device ID
    // 4      4     High nibble of the Device ID
    // 8      10*N  10bit axes (N is number of axes)
    // ?      8*N   8bit axes (N is number of axes)
    // ?      1*N   Buttons (N is number of buttons)
    // ?      R*N   Hats (R is resolution, N is number of hats)
    // ?      1*N   Secondary buttons (N is number of buttons)

    // Cyberman 2 seems not to work properly if the packets are
    // read too fast. Following delay will ensure, that after the
    // last read at least 5ms passed to ensure, that the joystick
    // cooled down again.
    delayMicroseconds(5000);

    const auto packet = readPacket();

    if (packet.size != m_metaData.packageSize) {
      return false;
    }

    const auto packetID = getBits(packet, 0, 4) | getBits(packet, 4, 4) << 4;
    if (packetID != m_metaData.deviceID) {
      return false;
    }

    State state;
    uint16_t offset = 8u;

    uint8_t axis = 0u;
    for (auto i = 0u; i < m_metaData.num10bitAxes; i++, axis++) {
      state.axes[axis] = mapAxisValue(axis, getBits(packet, offset, 10));
      offset += 10;
    }

    for (auto i = 0u; i < m_metaData.num8bitAxes; i++, axis++) {
      state.axes[axis] = mapAxisValue(axis, getBits(packet, offset, 8));
      offset += 8;
    }

    uint16_t button = 0u;
    for (auto i = 0u; i < m_metaData.numPrimaryButtons; i++) {
      state.buttons |= getBits(packet, offset++, 1) << button++;
    }

    if (m_metaData.hasHat) {

      const auto hatResolution = getHatResolution();
      state.hat = mapHatValue(getBits(packet, offset, hatResolution));
      offset += hatResolution;

      // Secondary hats are all shown as dual axes
      for (auto i = 0u; i < m_metaData.numSecondaryHats; i++, axis += 2) {
        const auto value = mapHatValue(getBits(packet, offset, hatResolution));
        offset += hatResolution;
        static constexpr uint16_t dx[] = { 511, 511, 1023, 1023, 1023, 511, 0, 0, 0 };
        static constexpr uint16_t dy[] = { 511, 0, 0, 511, 1023, 1023, 1023, 511, 0 };
        state.axes[axis + 0] = dx[value];
        state.axes[axis + 1] = dy[value];
      }
    }

    for (auto i = 0u; i < m_metaData.numSecondaryButtons; i++) {
      state.buttons |= getBits(packet, offset++, 1) << button++;
    }

    // If the device is a Logitech ThunderPad Digital, manually remap up, down, left and right buttons to X and Y axes
    if(m_metaData.deviceID == DEVICE_THUNDERPAD_DIGITAL){
      const auto value = getBits(packet, 12, 4);
      static constexpr uint16_t dx[] = { 511, 0, 511, 0, 1023, 511, 1023, 511, 511, 0, 511, 0, 1023, 511, 1023, 511 };
      static constexpr uint16_t dy[] = { 511, 511, 1023, 1023, 511, 511, 1023, 1023, 0, 0, 511, 511, 0, 0, 511, 511 };
      state.axes[0] = dx[value]; 
      state.axes[1] = dy[value];

      state.buttons &= 0xFF0F;
      state.buttons |= (state.buttons & 0x0F00) >> 4;
    }
    // If the device is a Logitech WingMan Gamepad, manually remap up, down, left and right buttons to X and Y axes
    else if(m_metaData.deviceID == DEVICE_WINGMAN_GAMEPAD){
      const auto value = getBits(packet, 8, 4);
      static constexpr uint16_t dx[] = { 511, 0, 511, 0, 1023, 511, 1023, 511, 511, 0, 511, 0, 1023, 511, 1023, 511 };
      static constexpr uint16_t dy[] = { 511, 511, 1023, 1023, 511, 511, 1023, 1023, 0, 0, 511, 511, 0, 0, 511, 511 };
      state.axes[0] = dx[value]; 
      state.axes[1] = dy[value];

      state.buttons >>= 4;
    }

    m_state = state;
    return true;
  }

  const State &getState() const override {
    return m_state;
  }

  const Description &getDescription() const override {
    return m_description;
  }
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

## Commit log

2020-11-23 Add gerber files, minor cleanup
    [gameport-adapter-B_Cu.gbr, gameport-adapter-B_Mask.gbr, gameport-adapter-B_Paste.gbr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]
2020-11-23 Update LSCS part number
    [gameport-adapter.sch]
2020-11-28 Set proper LCSC part number for the gameport
    [gameport-adapter.sch]
2020-11-28 Updated PCB
    [gameport-adapter.kicad_pcb]
2021-01-07 Switched to Arduino Pro Micro
    [gameport-adapter-B_Cu.gbr, gameport-adapter-B_Mask.gbr, gameport-adapter-B_Paste.gbr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]
2021-01-07 Updated LCSC part numbers
    [gameport-adapter.sch]
2021-03-12 Add pull-down resistors to analog pins
    [gameport-adapter-B_Cu.gbr, gameport-adapter-B_Mask.gbr, gameport-adapter-B_Paste.gbr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]
2021-04-01 OSHW logo, silk layer fixes
    [gameport-adapter.kicad_pcb, gameport-adapter.sch]
2021-04-20 Move socket towards connector
    [gameport-adapter.kicad_pcb]
2021-04-27 Rotated switch order
    [gameport-adapter.kicad_pcb, gameport-adapter.sch]
2021-04-28 Add initial support for ThrustMaster
2021-05-04 Massive refacturing.
    - Extracted AnalogJoystick parts
    - Improved DigitalPin
    - Renamed Joystick -> Driver
    and more...
2021-05-14 Implemented Sidewinder driver (working)
2021-05-14 Set Hat Switch range to 1-8
2021-05-15 Renamed all drivers to HidClass
2021-05-15 Fix potential null pointer
    [gameport-adapter.ino]
2021-05-16 Add image, add BOM, known issues etc...
2021-05-17 Add JoystickB4A3 driver, switches reordered
2021-05-30 Fix USB z-axis IDs
2021-05-31 Increased input buffer again.
    The size of input buffer should be higher, than the biggest possible
    input length. In case the joystick transmits more bits, than expected,
    it can be used for error detection.
2021-06-01 Code format, switch case allignment
2021-10-20 Reimplement Packet.print() and remove some logs.
2021-10-20 Update Description for sidewinder FFB wheel
2021-10-22 Add Sidewinder Wheel to the list of supported devices
2021-10-31 Switched Sidewiner to the new USB implementation
2021-10-31 Reduced footprint of static data
2021-10-31 Switched GrIP to the new USB implementation
2021-10-31 Fixed device ID position in the HID description
2021-11-01 Reduce memory footprint.
    Joystick name doesn't need to be copied, it's sufficient to use a
    simple C-string. This way 32 bytes for each joystick model can be
    saved.
2021-11-01 Fix device name to C string pointer
    [Logitech.h]
2021-11-01 Add secondary buttons
2021-11-01 Add Logitech to the list of supported devices in the README
2021-11-04 Switched to standard Buffer
2021-11-05 Add 3bit/1bit mode support for the FFB Wheel
2021-11-08 Fix buttons axes count for generic joystick
    [gameport-adapter.ino]
2021-11-15 Add delay between the updates for Logitech devices
2021-11-16 Add CyberMan2 to the list of supported devices.
    Made some markdown reformat.
2022-01-01 Add QuickShot QS-123E into tested devices
2022-01-19 Minor silk layer fixes, rev 0.2.1
    [gameport-adapter.kicad_pcb]
2022-03-19 Update gitignore to ignore gerber folder in kicad folder
    When generating the gerber files necessary for printing the PCB, the default output from Kicad is to put them into a subfolder of the folder containing the .pro folder, named gerber. Add a rule to th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
2022-03-20 Add Mouser Electronics to BoM; Update LCSC DIP24 Socket part number
    The new LCSC part number is more similar to the Digikey option.
2022-03-20 Correct DIP Switch part at Mouser
2022-03-30 Revert back to original DIP24 Socket at LCSC
2022-06-20 Update GamePort.h
    Added descriptive information which GamePort pin is connected to the Arduino pin
2022-06-20 Fix currently unused GamePort<12> pin designation
    GamePort<12>should be pin 5 instead of pin 20, as pin 20 is already occupied by the DIP switch
2022-06-21 Improve switch detection.
    Reading digital inputs in setup seems not always to work reliably, so
    the initialization moved into the loop and is triggered on the first
    iteration.
2022-06-21 Update the list of tested devices
2022-06-22 replace function delay() with delayMicroseconds()
    Replacing the only occurence of delay(5) with delayMicroseconds(5000) saves 72 bytes.
    In the corresponding asm file at address 0000031a this replaces the function
    <delay>with a shorter <delay.constprop.22> instruction.
    [Logitech.h]
2022-06-25 Upgrade project to KiCad 6.x
    [gameport-adapter.kicad_pcb, gameport-adapter.kicad_sch, gameport-adapter.sch]
2022-06-29 enable debug feature (Logitech.h)
    DEBUG_LOG( ) is getting replaced to log( ) during compilation, when __DEBUG__ is defined
    [Logitech.h]
2022-06-29 Update gameport-adapter.ino
    corrected sentence structure
    [gameport-adapter.ino]
2022-06-29 Remove unused print( ) function in Buffer.h
2022-06-29 Update Utilities.h
    switch to NDEBUG
2022-06-29 Update gameport-adapter.ino
    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
2022-06-29 Some minor comment fixes
    [gameport-adapter.ino]
2022-06-29 Added switchable debug feature, remove unused print( ) function (#33)
    * enable debug feature (gameport-adapter.ino)
    * enable debug feature (Utilities.h)
    include DEBUG_LOG(...) definition here as it get included in all necessary files
    * enable debug feature (Logitech.h)
    * enable debug feature (HidJoystick.h)
    * enable debug feature (Sidewinder.h)
    * Update gameport-adapter.ino
    added DEBUG information
    * Update gameport-a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
    [Logitech.h, gameport-adapter.ino]
2022-06-29 Revert "Added switchable debug feature, remove unused print( ) function (#33)"
    This reverts commit 4b660cee41e534d15c8490c27ae6d526d54ff37d.
    [Logitech.h, gameport-adapter.ino]
2022-09-13 Added driver for CH F16 Combat Stick
2022-09-14 Hardened CH F16 code for buttons decoding
2022-09-25 Refilled ground zones
    [gameport-adapter.kicad_pcb]
2023-02-02 Refactoring and switch to universal readID function
2023-07-21 Add small delay to the initialization.
    Some arduinos seem not to get the input pins in time before the switch
    for the device type is been read. This can lead to incorrect joystick
    type report. Adding a delay between input pin setup and actual read
    should improve that behavior.
2023-09-20 Fix timeout for Logitech Wingman Interceptor
    [Logitech.h]
2023-10-19 Refer to the GrIP Linux driver in the GrIP code
2024-02-17 Added Logitech WingMan Light to the table (#81)
2024-05-05 Update list of tested devices
2024-12-03 Add support for Logitech WingMan Gamepad (#95)
    Thank you for the contribution.
2025-06-06 Update README.md
    Add tested ThrustMaster models

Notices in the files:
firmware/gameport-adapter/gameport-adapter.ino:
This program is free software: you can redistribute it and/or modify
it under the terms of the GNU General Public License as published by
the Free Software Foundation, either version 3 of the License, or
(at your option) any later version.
